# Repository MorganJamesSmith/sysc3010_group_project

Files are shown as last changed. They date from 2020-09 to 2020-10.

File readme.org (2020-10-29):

#+title: SYSC3010 Group Project
* Table of Contents                                          :TOC_1:noexport:
- [[#symptom-monitoring-door-system][Symptom monitoring Door System]]
- [[#possible-hardware][Possible hardware]]
- [[#group-expectations][Group Expectations]]
- [[#group-roles][Group Roles]]
- [[#weekly-meeting-guidelines][Weekly Meeting Guidelines]]
- [[#project-meeting-notes][Project Meeting Notes]]

* Symptom monitoring Door System
** Terminology
To keep a consistent style please use the following terms. No synonyms please
- Door Node
- Control Server
  - Users have: Accounts
- Security Badge
- NFC security badge reader
- infrared temperature sensor
- electronic lock actuator
** Description
The purpose of this system is to increase security and safety of
secured locations, like offices. The system will attempt to prevent
the spread of illness by limiting the number of people which can enter
the building, and by preventing people with a high body temperature
from entering the building.

This system will be mounted on the entrances and exits of a
building. The system will be modular to allow an arbitrary number of
nodes to be added.

The system will display a green light at the entrance if it is
accepting people. The light will turn red when the area is closed or
if there are too many people inside.

If the light is green, the user will present their NFC security card
to the system. The system send a message containing a unique user ID
to a server. The server will use it'd database to determine if the
user is authorized and if the user had previously shown symptoms to
the system within the last 14 days. The server will then notify the
door with the results of the query.

If the user has not already been denied, the system will then take the
user's temperature. If the temperature is above the threshold, they
can try again in 1 minute. If they fail 3 times in a row, they will be
forbidden access, and the operator of the system will have the option
to automatically deny them entry for the duration of a quarantine
period.

Every access attempt, including the associated temperature reading and
user ID, is sent to the server to be logged in a database.

If the temperature is below the threshold, and they have access, the
door will open.

Users will also have to present their NFC card to the door to leave
the building. By tracking users entering and exiting the building, the
server will know how many people are in the building.

The central server will also provide a GUI available to the buildings
security team. This GUI will allow security officers to manually
update the status of individuals in case a door must fall back to
manual operation. It will also allow the security team to modify who
has access to the building. For example, if someone receives a
negative test result for COVID-19, their access to the building could
be restored.

** Hardware
- 3D printed scale model of door
- Servo
- Contact-less Temperature Sensor
- NFC reader + cards
- Raspberry Pi's
** Requirements
*** Computer Components [3/3]
- [X] Computer per student
  - Computer for each entrance and exit
  - Database computer
- [X] computer in standalone mode
  - Interface for security team
    - Allow manual modification of user status
    - View temperature information on each person
- [X] computer in headless mode
  - Computers at entrances and exits
*** Hardware Components [2/3]
- [X] Actuator
  - Door opener
- [X] one sensor per student
  - Temperature probes
- [ ] Feedback loop
  - Door opens in response to temperature
*** Software Components [5/7]
- [X] Database
  - Number of people inside building
  - Uniquely identify people via smart card
- [X] Computer hosting database does something else
  - Runs GUI
- [ ] Periodic Timing Loop
  - Restrict access to when building is open
- [ ] Data processing
  - Access control
  - View interaction history
- [X] Notifications
  - Notify on failure and when near capacity
  - Notify if known infected people try to enter
- [X] Communication (through thingspeak)
  - Synchronize Database
- [X] GUI
  - See security team interface

* Possible hardware
** Temperature Sensor
- [[https://www.melexis.com/en/product/MLX90614/Digital-Plug-Play-Infrared-Thermometer-TO-Can][MLX90614]]
    - Very popular IR thermometer in TO-can
    - MLX90614ESF-DAA is the medical version, MLX90614ESF-BAA is the non medial
      3 V version
    - In stock at [[https://www.sparkfun.com/products/9570][SparkFun]]
- [[https://www.excelitas.com/product/tpis-1t-1256-l55-digipile-sensor][TPIS 1T 1256 L5.5]]
    - Designed for ear and forehead temperature measurement applications
    - 5 degree field of view
    - 67 counts per degree kelvin for a 40 ℃ object at 25 ℃ ambient, 8 counts per kelvin of noise for same conditions
    - Also measures ambient temp
    - Very annoying badly documented single wire digital interface, may be a bit
      tricky to get working directly on R-Pi but we could always use a small
      microcontoller like an ATTiny as a bridge
    - In stock at [[https://www.digikey.ca/en/products/detail/excelitas-technologies/TPIS-1T-1256-L5-5/5885902][DigiKey]]
** NFC
- [[https://www.nxp.com/docs/en/nxp/data-sheets/PN532_C1.pdf][Adafruit breakout for PN532]]
    - Seems to be compatible with [[https://github.com/nfc-tools/libnfc][libnfc]]
    - I2C, SPI and UART interfaces (Adafruit seems to strongly recommend SPI for
      use with the Raspberry Pi, but that could be a limitation of their
      CircuitPython library)
    - Comes with a MiFare Classic 1K card
    - Can get MiFare Classic in many different form factors (cards, keychains,
      rings, bracelets, etc.) from Adafruit or Sparkfun.
- [[https://www.nxp.com/products/rfid-nfc/nfc-hf/nfc-readers/explore-nfc-exclusive-from-element14:PNEV512R][NXP EXPLORE-NFC-WW]]
    - R-Pi hat based on [[https://www.nxp.com/docs/en/data-sheet/PN512.pdf][PN512]]
    - Cheaper than the Adafruit option and it's a nice hat form factor, but it
      is only available from [[https://canada.newark.com/nxp/explore-nfc-ww/nfc-add-on-board-raspberry-pi/dp/45X6356][Newark]]
      and they have not been reliable lately.
- Mario has a module based on the [[https://www.nxp.com/docs/en/data-sheet/MFRC522.pdf][MFR522]]
    - Slightly older chip than the others, but it should support everything we
      need
    - Might be hard to reliably find exactly the same board for other group
      members, it came as part of a kit and seems to be one of those Ali-Express
      type things. It would probably be possible to find other boards with the
      same chip though

* Group Expectations
- Slack messages will be responded to within 1 work day.
* Group Roles
** Sam
- Submit deliverables
** Sunny
** Mario
** Morgan
- Meeting Secretary
* Weekly Meeting Guidelines
- Happens every Tuesday @ 09:30
- Reminder should be sent in slack group chat the previous night
- Meeting is voice chat @ https://meet.jit.si/wewantbird
- Morgan takes notes and adds them to this document

1. Deliver Reports of what was accomplished since last meeting
2. Discuss any impediments
3. Discuss any impediments expected for the next week (example: lack
   of time due to midterms or travel)
4. Assign work for the next week
* Project Meeting Notes
** Meeting 9 <2020-10-28 Tue 18:00-22:00>
*** Minutes
Worked on design document.
*** TODOs
**** Everyone
- Write hardware stubs for your hardware
**** Sam
- Make electronic-lock-schematic.png slightly prettier
- Combine all class diagrams
- Add electronic lock to ?? schematic
- Create python classes to facilitate message transfer
**** Mario
- Flow chart stuff
  - Based off of class diagrams to be done by Sam
- Add more tests
- Reformat and sort tests
- Make list in problem statement a group of functional requirements (in terms
  of tasks or behaviors) instead of a list of parts
  - Prioritize the functional requirements
***** Sam's comment that might help you
Functional requirements:
- Control access to a building using security badges.
- Require users to present their security badge when they enter or exit the
  building in order to track the number of users in the building.
- Measure user's temperatures when they are entering the building in order to
  determine if they have possible symptoms.
- The door node should have a range sensor to determine whether users are in
  an appropriate position for a temperature reading.
- Do not allow more users to enter the building if the a preset maximum
  capacity has been reached.
- An multicoloured LED at each door node should indicate be used to indicate
  the status of the door node. The LED should be normally red when the door is
  locked and should change to green when the door is unlocked. The LED should
  be orange when in the process of taking a temperature reading if the user is
  not within an appropriate range of the temperature sensor.
**** Sunny
- Please write a description of the database schema
- Update database schema
- End-to-end tests
- Create database test stub
** Meeting 8 <2020-10-20 Tue 09:30>
*** Agenda
- Design Peer Review Integration
** Meeting 7 <2020-10-13 Tue 09:30>
*** Minutes
- Sam demoed his ThingSpeak code (very cool, much wow)
- Determined project design schedule
*** Project Design Roles
- flow chart for testing
**** Sam
- demo plan 3
- design overview text
- software design text
- Hardware design text
- temperature sensor
  - relevant hardware specification
  - test plan 2 a
- communication protocol table
- Related Class diagrams
- door node circuit diagram
**** Sunny
- Problem statement
- Project Update
- Database table design (help from Sam)
- Related Class diagrams
- test plan demo plan 1
- test plan demo 2 b
**** Mario
- NFC
  - relevant hardware specification
  - test plan 2 a
- Related Class diagrams
- flow chart for door interface
- flow chart for server:door messaging
**** Morgan
- motor
  - relevant hardware specification
  - test plan 2 a
- UML Architectural diagram
- Message sequence diagram(s)
- Related Class diagrams
** Meeting 6 <2020-10-06 Tue 09:30-10:10>
*** Minutes
- preliminary project design discussions
** Meeting 5 <2020-10-01 Thu 08:30-10:15>
- Reviewed proposal feedback and made changes
** Meeting 4 <2020-09-29 Tue 09:30-11:30>
*** Agenda
- Review proposal draft together
*** Minutes
- We reviewed the proposal and made some changes
*** TODOs
- Everyone: Touch up proposal as we discussed
- Morgan: Email the prof asking if we should include the actors in our
  deployment diagram
** Meeting 3 <2020-09-22 Tue 09:30-11:00>
*** Agenda
- Research project concepts
  - Look into hardware price/availability/complexity
*** Completed
- Finalized Project Idea
*** TODOs
- Everyone: Review proposal draft posted on Monday and bring written
  comments to next meeting
- Sam: Update readme with hardware research
- Morgan: Email Prof to confirm our project concept is approved
**** Proposal
***** Timeline
****** Content
<2020-09-27 Sun 12:00>
****** Latex formatting + send PDF to slack
<2020-09-28 Mon>
***** Sunny
- Executive Summary
  - Problem Statement
  - Motivation
  - Objective
  - Goals
  - Scope
***** Morgan
- deployment diagram
- door usage diagram
- hardware block diagram
***** Sam
- Test Plan
- Milestones and Timeline
- Latex formatting
***** Mario
- proposed solution
  - Server database
  - GUI
  - Integrate Morgan's diagrams
** Meeting 2 <2020-09-18 10:00-12:20>
*** Agenda
- Discuss Project Ideas
- Finalizing team contract
*** Completed
- Team contract
- Initial draft of proposal of a door monitoring system
** Meeting 1 <2020-09-17 10:30-11:30>
- Assigned Morgan "Secretary" role for weekly meetings
- Assigned Sam "Submit deliverables" role
- Created meeting guidelines (found [[https://github.com/MorganJamesSmith/sysc3010_group_project/blob/master/readme.org#weekly-meeting-guidelines][here]])
- Discussed team contract
- Created a readme to track progress, expectations, and meeting notes
  (found [[https://github.com/MorganJamesSmith/sysc3010_group_project/blob/master/readme.org][here]])
- Scheduled Meeting 2
*** To be completed before meeting 2
- All members: Review
  https://github.com/MorganJamesSmith/sysc3010_group_project/blob/master/readme.org
  and provide comments
- All members: Review all project requirements (Fact check + add information to
  this readme)

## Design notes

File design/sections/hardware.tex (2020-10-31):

The door node is the hardware that will be located at each door. It consists of
a NFC security badge reader, infrared temperature sensor, time of flight range
sensor and electronic door lock, all connected to a Raspberry Pi.

Figure \ref{fig:door-node-schematic} shows a schematic of the door node.

\begin{figure}[!htb]
\centering
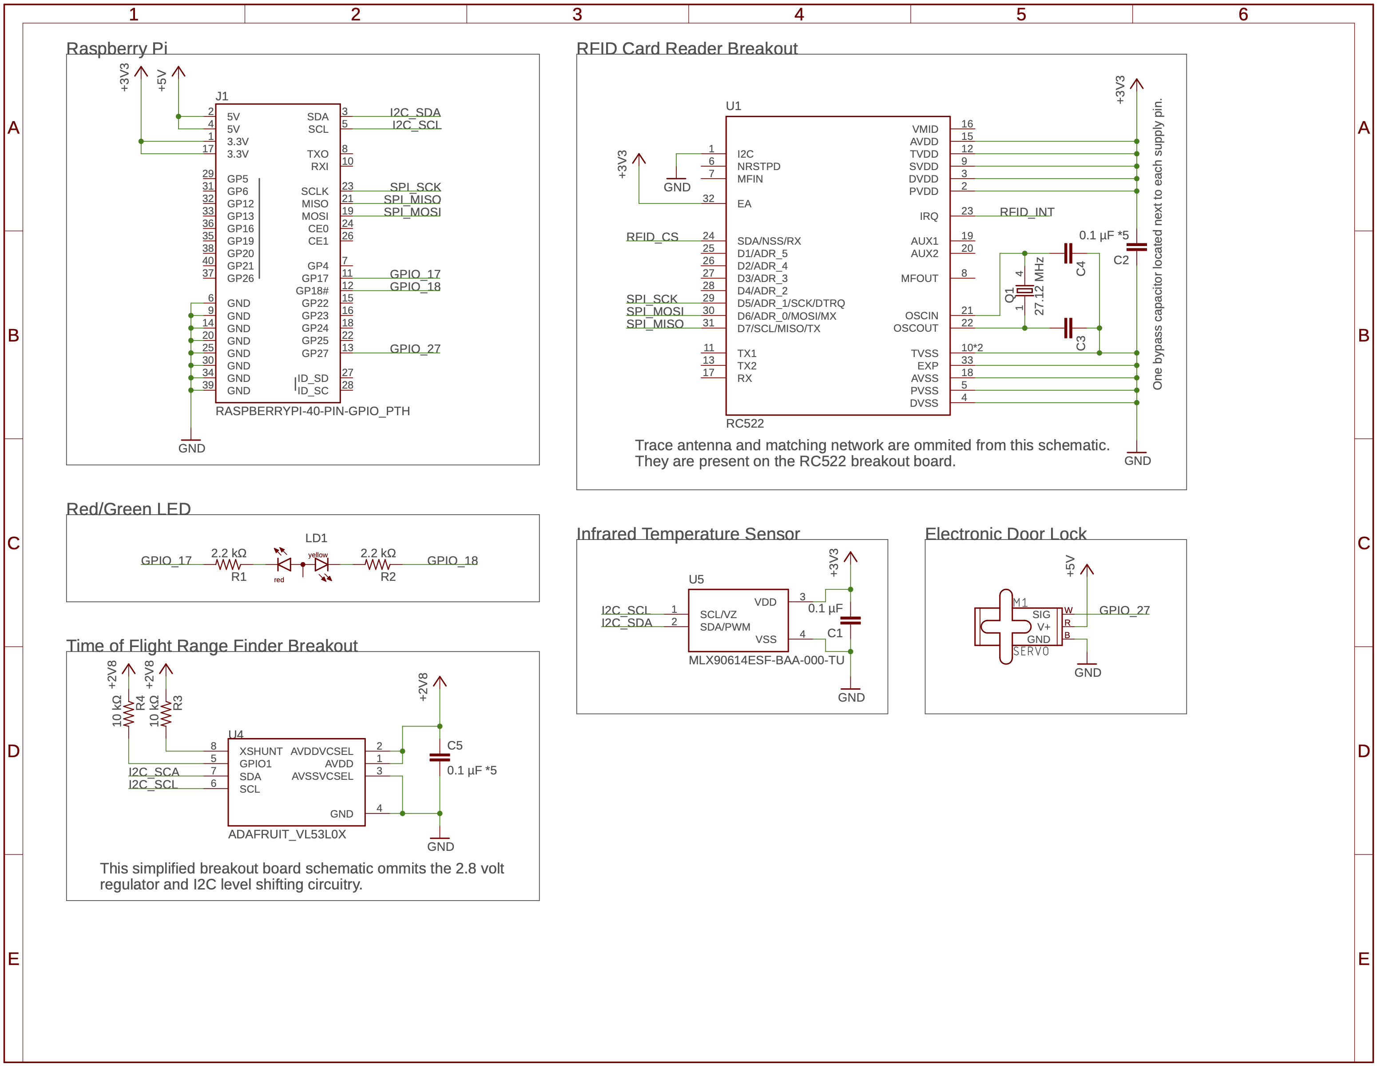
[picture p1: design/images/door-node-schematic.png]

\caption{Door Node Schematic}
\label{fig:door-node-schematic}
\end{figure}

\subsection{Infrared Temperature Sensor}

In order to detect fever we need to measure the temperature of the users of our
system. We have determined that a forehead temperature measurement using an
infrared temperature sensor is the best way to obtain sufficiently accurate
contactless temperature measurements.

We plan to use the MLX90614 thermopile from Melexis Technologies. This
temperature sensor was chosen after a comparison of available infrared
temperature sensors.

The MLX90614 offers medical grade accuracy within the temperature range expected
for human skin. It also provides accurate ambient temperature measurements. The
optics of the sensor provide a relatively narrow field of view which is
appropriate for measuring the fairly small target of a human forehead from a
reasonable range.

The MLX90614 can be powered from the Raspberry Pi's 3.3 volt rail and
features an I$^2$C serial interface, which is suitable for communication with a
Raspberry Pi.

Figure \ref{fig:ir-test-circuit} shows the test circuit for the infrared
temperature sensor.

\begin{figure}[!htb]
\centering
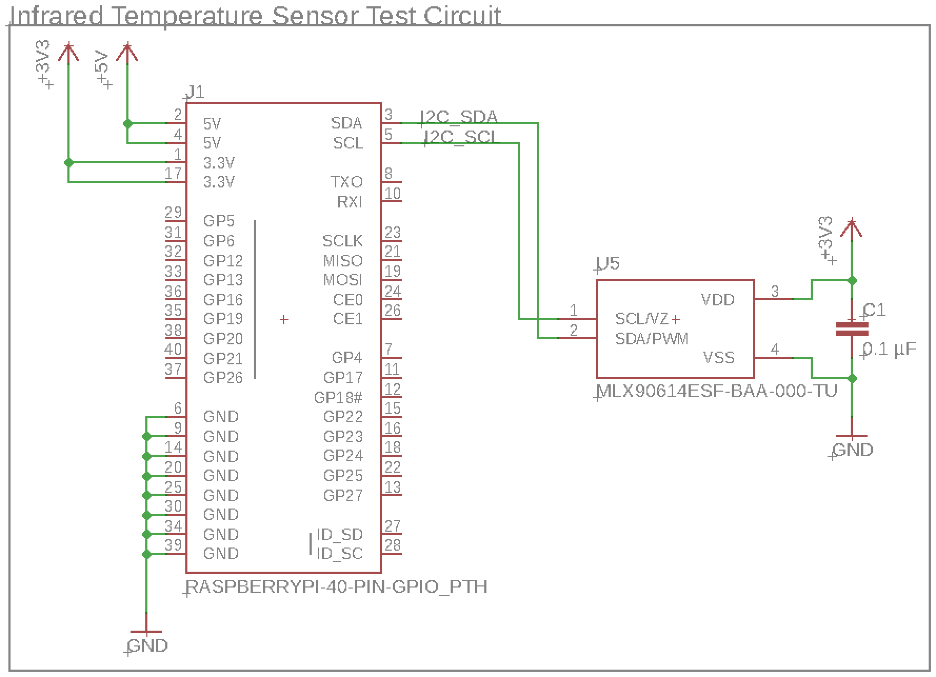
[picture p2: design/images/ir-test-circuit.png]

\caption{Test Circuit for Infrared Temperature Sensor}
\label{fig:ir-test-circuit}
\end{figure}

\subsection{NFC Security Badge Reader}

The MFRC522 RFID reader is the chosen device for the NFC security badge reader. 
It has an operating distance of up to 50 mm which means that the users will not have to place
the card almost touching the reader. the fact that it includes a programmable timer
is very useful as it can help avoid creating issues where it scans a card multiple times 
when doing a single swipe. As the reader is not meant to be the end all of deciding 
whether or not an employee will unlock the door it is therefore useful that the device
supports power down by software mode. When in lockdown or an employee attempts
to enter the building at full capacity it will be powered-down preventing entrance.  
The usage of serial peripheral interface helps as the badge reader functions quickly 
being able to handle data speeds up to 10 Mbit/s. 
It is powered by the 3.3 V DC power source of the Raspberry Pi.

For the below test circuit the differences between the test circuit and the actual demo circuit
are as follows. The T GPIO extension board used is coloured differently
and indicates GPIO rather than "\#" before the numbers. 
Other then those two changes the below circuit is identical to that which will be used in demonstrations.

\begin{figure}[!htb]
\centering
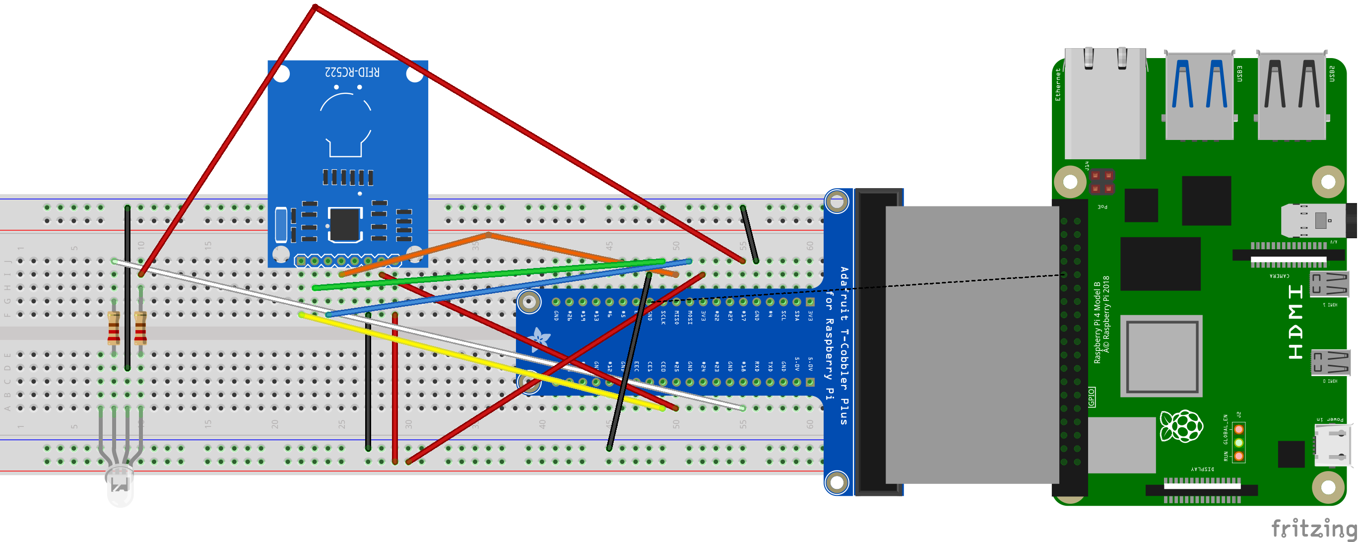
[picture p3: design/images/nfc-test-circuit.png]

\caption{Test Circuit for NFC Security Badge Reader}
\label{fig:nfc-test-circuit}
\end{figure}

\subsection{Electronic Door Lock}

The electronic door lock model will be powered by a servo motor. The chosen
servo motor is the Adafruit Micro Servo.  This servo has 180 degrees of motion
that can be traversed in 0.3 seconds.  The servo operates between 3V and 6V so
it can be powered through the Raspberry Pi's 5V line.

Figure \ref{fig:lock-test-circuit} shows the test circuit for the electronic
door lock.

\begin{figure}[!htb]
\centering
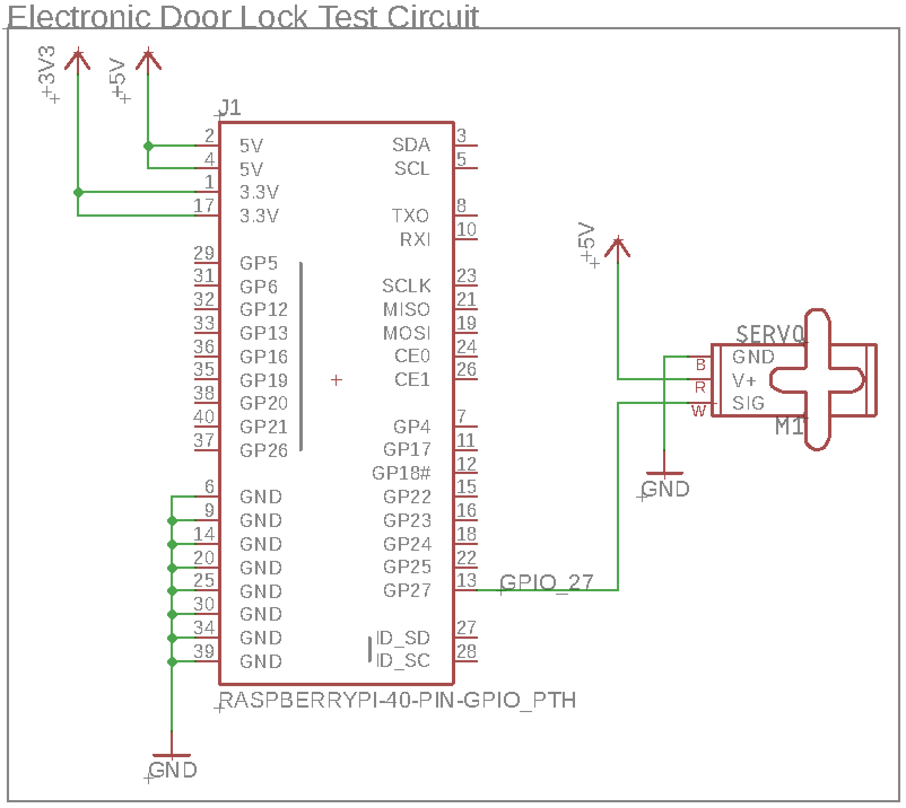
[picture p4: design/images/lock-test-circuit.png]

\caption{Test Circuit for Electronic Door Lock}
\label{fig:lock-test-circuit}
\end{figure}

\subsection{Time of Flight Range Sensor}

\begin{figure}[!htb]
\centering
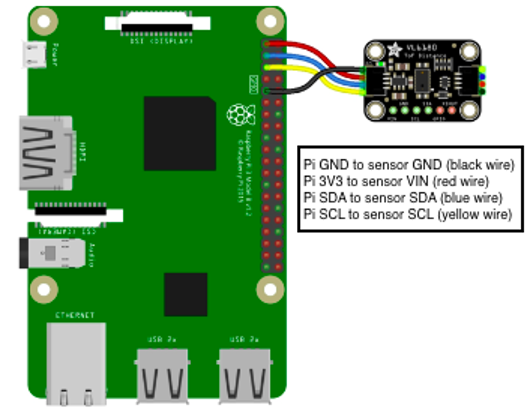
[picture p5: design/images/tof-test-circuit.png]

\caption{Test Circuit for Time of Flight Sensor}
\label{fig:tof-test-circuit}
\end{figure}

\subsection{Control Server}

The control server hardware will consist of a Raspberry Pi connected to a
monitor, keyboard and mouse.

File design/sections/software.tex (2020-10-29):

\subsection{Class Diagram}

\begin{figure}[!htb]
\centering

\caption{Class Diagram}
\label{fig:class-diagram}
\end{figure}

\subsection{Door Node}

\begin{figure}[!htb]
\centering
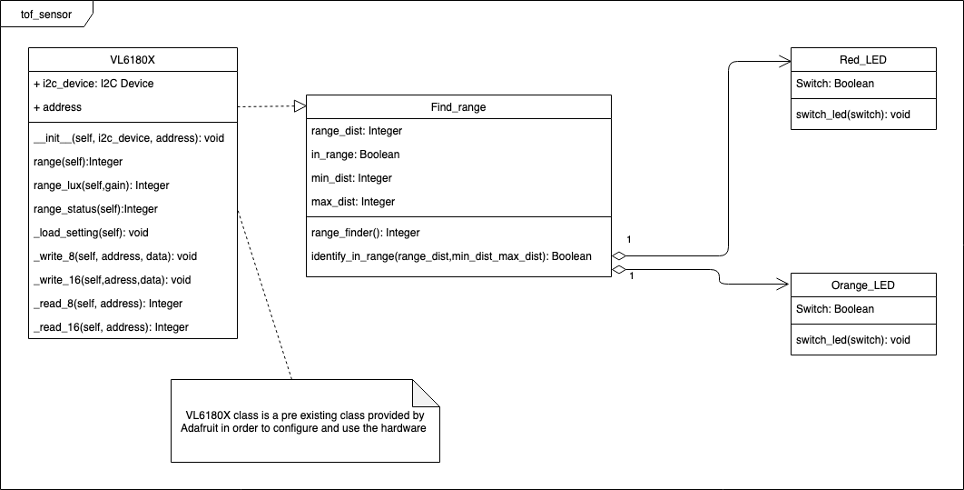
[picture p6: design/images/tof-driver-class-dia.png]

\caption{Class Diagram for Time of Flight Range Sensor Driver}
\end{figure}

\begin{figure}[!htb]
\centering
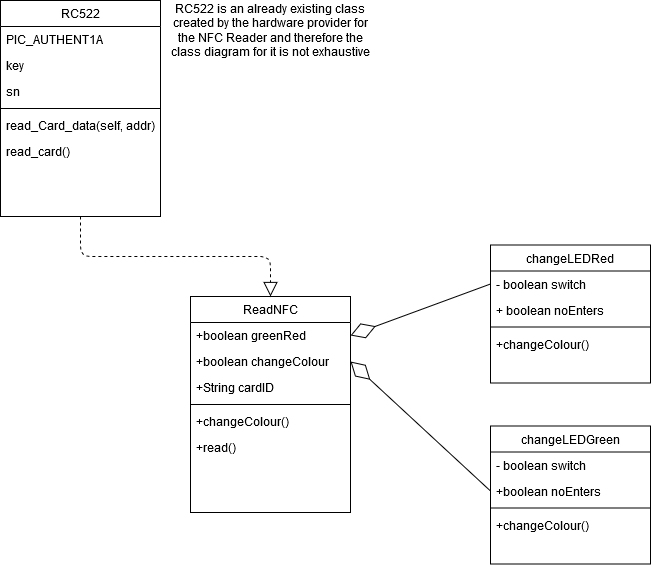
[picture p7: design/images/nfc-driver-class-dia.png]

\caption{Class Diagram for NFC Security Badge Reader Driver}
\end{figure}

\begin{figure}[!htb]
\centering
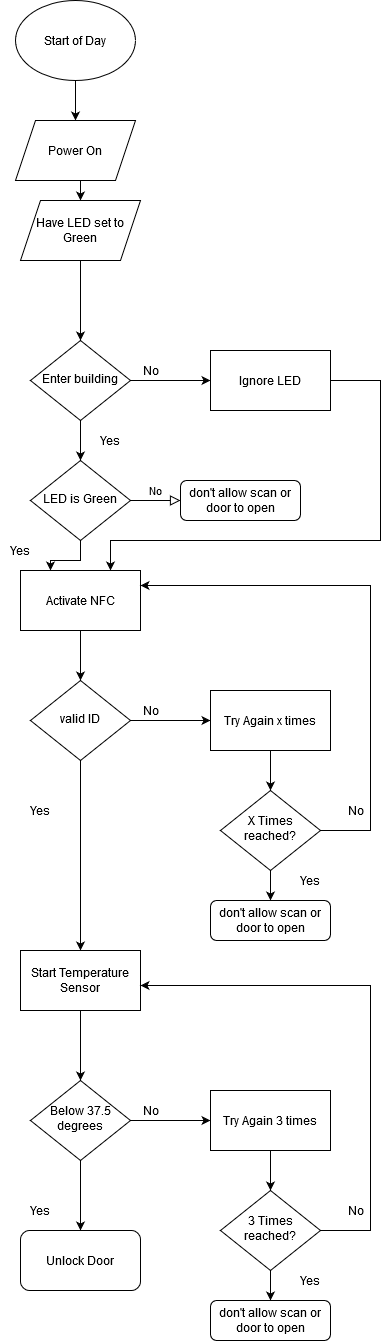
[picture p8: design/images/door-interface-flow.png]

\caption{Flow of Door Node Software}
\end{figure}

\subsection{Control Server}

\begin{figure}[!htb]
\centering
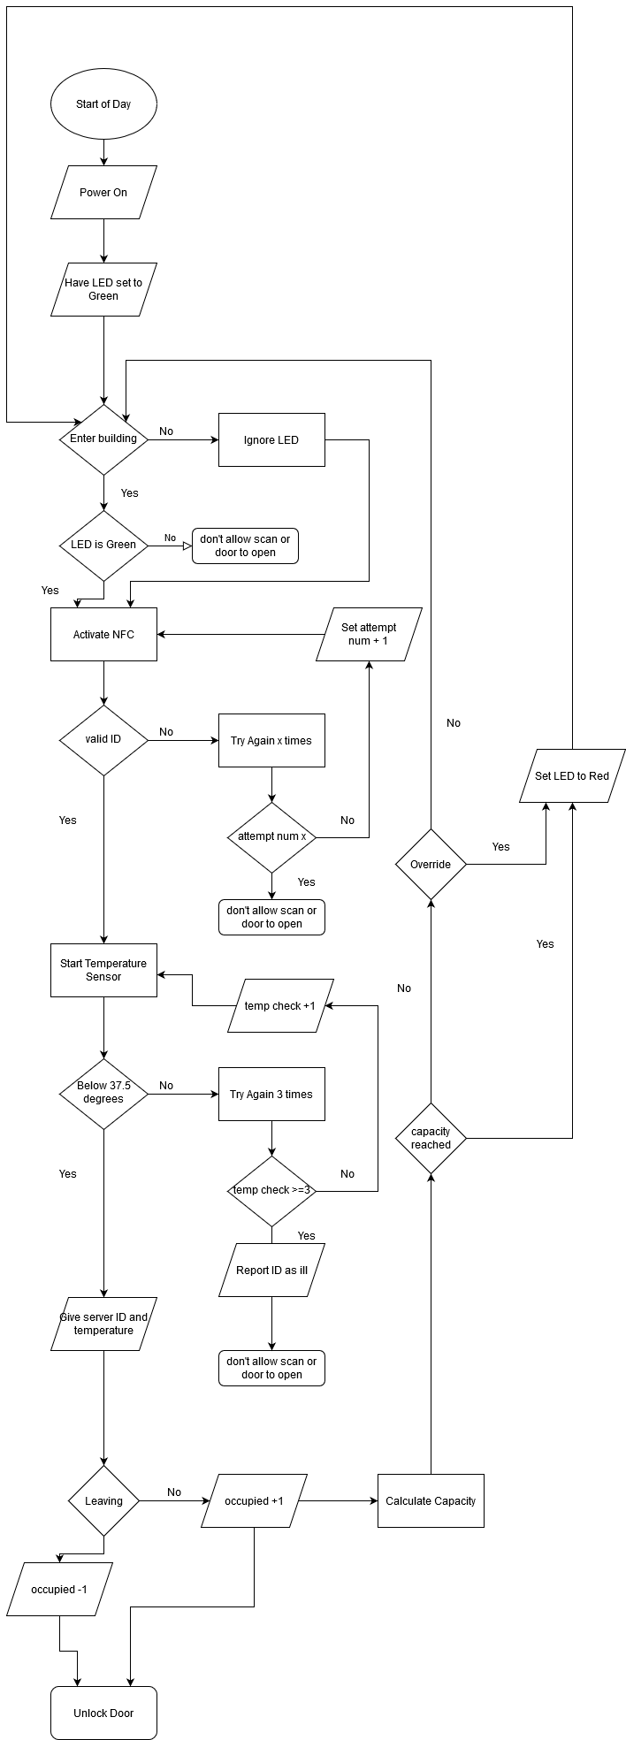
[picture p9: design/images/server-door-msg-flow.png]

\caption{Flow of Communication Between Control Server and Door Node}
\end{figure}

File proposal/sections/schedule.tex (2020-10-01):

\subsection{Timeline}

Table \ref{table:timeline} shows important submission deadlines and when we plan
to have major milestones completed.

\begin{table}[!hbt]
\renewcommand\arraystretch{1.4}\arrayrulecolor{LightSteelBlue3}
\captionsetup{singlelinecheck=false, font=blue, labelfont=sc, labelsep=quad}
\caption{Timeline}\vskip -1.5ex
\begin{tabular}{@{\,}r <{\hskip 2pt} !{\foo} >{\raggedright\arraybackslash}p{10cm}}
\toprule
\addlinespace[1.5ex]
2020-10-02 & Submission: Project Proposal\\
2020-10-11 & Milestone: Complete Initial Research\\
2020-10-14 & Milestone: Complete Communication Code\\
2020-10-23 & Submission: Project Design\\
2020-11-01 & Reflection: Re-evaluate Project Timeline\\
2020-11-01 & Milestone: Complete Door Model\\
2020-11-08 & Milestone: Complete Hardware Interface Code\\
2020-11-15 & Milestone: Complete Application Code\\
2020-11-22 & Milestone: Complete User Interface Code\\
2020-11-25 & Submission: Code Peer Review\\
2020-12-09 & Submission: Final Report\\
\end{tabular}
\label{table:timeline}
\end{table}

\subsection{Milestones}

\paragraph{Complete Initial Research}
By this point we should have completed all of out research in order to select
what hardware and libraries we would like to use for our project.

\paragraph{Complete Hardware Interface Code}
By this point all of the code responsible for interfacing with hardware and all
of the associated test stubs and applications should be complete. Work on this
milestone can be done in parallel with work on the communication and application
code.

\paragraph{Complete Communication Code}
By this point all of the code for exchanging information between door
nodes and the control server as well as all of the associated test stubs and
applications should be complete. Work on this milestone can be done in parallel
with work on the hardware interface and application code.

\paragraph{Complete Door Model}
By this point a 3D printed model door will be attached to a servo
attached to a Raspberry Pi with appropriate drivers.

\paragraph{Complete Application Code}
By this point all of the application level code should be complete and we should
be performing integration testing. Work on this milestone can be done in
parallel with work on the hardware interface and communication code.

\paragraph{Complete User Interface}
By this point the graphical user interface should be complete. We should be
performing integration testing of our complete system. Work on this milestone
can be done in parallel with work on the application code.

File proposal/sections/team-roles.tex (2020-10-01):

\subsection*{Sam}
\begin{itemize}
    \item Infrared Temperature Sensor
    \item ThingSpeak Communication
\end{itemize}

\subsection*{Sunny}
\begin{itemize}
    \item Database
    \item Data Processing
    \item Request Handling
\end{itemize}

\subsection*{Mario}
\begin{itemize}
    \item NFC Security Badge Reader Drivers
    \item Door Node User Interface
\end{itemize}

\subsection*{Morgan}
\begin{itemize}
    \item Operator GUI
    \item Make a prototype door actuator
    \begin{itemize}
        \item Servo drivers
        \item 3D printed door
    \end{itemize}
\end{itemize}

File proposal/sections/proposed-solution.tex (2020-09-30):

\subsection{Deployment Diagram}



\subsection{Communication Between Nodes}
The door nodes will communicate with with the control server using ThingSpeak.
They will send send messages to the control server on each user interaction and
the control server will provide information to them on whether users should be
granted access and what the door node's LED should show.

\subsection{Door Nodes}
The door nodes are Raspberry Pis that are set up in headless mode. The door
nodes are the  main points of interaction for the system, they have an NFC
security badge reader, an infrared temperature sensor and an electronic lock
actuator. An LED is connected to each of the door nodes that can be illuminated
in red or green to indicate whether people are allowed to enter the area.

% \subsubsection{Hardware Block Diagram for Door Hardware}

\subsubsection{Usage Diagram for Door}



\subsubsection{Sensors}
The infrared temperature sensor is central to the safety of the location
and why the system exists. It can measure the temperature of an individual
without physically touching them. The temperature information will be
communicated to the control server which can use it to determine if the users
has a fever and, if they do, will deny them access.

The NFC security badge reader is used to identify users. The control server will
keep track of users, including their access permissions and history of possible
symptoms, based on their security badges.

\subsubsection{Actuator}
The door will be unlocked by an electronic lock actuator attached to it. The
actuator will be controlled based on permission being granted by the control
server. The electronic lock by default will require an NFC security badge when
entering the building or leaving it. However, there will be failsafes so that if
there is a power outage or emergency it can be kept either locked or unlocked.

\subsection{Control Server}
The control server will be a Raspberry Pi connected to a monitor, keyboard and
mouse. The control server will maintain the database and will be responsible for
making decisions on whether to grant access to individuals based on the
configured access controls, the sensor data reported by the door nodes and the 
number of people currently in an area. 

The control server will also have a user interface that can be used for managing
the system.

\subsubsection{Database}
The database will contain the information about the individuals with valid
security badges. The database records will include information the temperature
measurements and the times at which people entered and left the building as well
as information about the access policy for entering the building.

\subsubsection{Graphical User Interface}
The Graphical User Interface (GUI) of the control server will appear as a table
with menus for options for the operator to view and interact with the database 
and the control server in a visually clear fashion. This includes being able to
set ranges for temperature, override the current LED colours and approving
quarantining.

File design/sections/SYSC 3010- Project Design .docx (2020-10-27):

SYSC 3010- Sunny Project Design Components

Problem Statement:

Our access control system will be designed to meet the needs of employers to look after the safety of their employees. The scope of this project is to provide employers with an access control system that grants access to employees entering the workplace based on their measured body temperature. As studies show that fever (< 39.1 °C) is the most frequent symptom in more than 50% of COVID-19 cases [1 (https://www.cebm.net/covid-19/in-patients-of-covid-19-what-are-the-symptoms-and-clinical-features-of-mild-and-moderate-case/)] our system also blocks access to employees with a body temperature of over 39.1 °C for 14 days to prevent the spread of COVID-19 in the workplace. Additionally, our system adheres to social distancing guidelines implemented by the government by keeping track of the number of people on the premises and restricts employees from entering the building when the maximum threshold for the workplace has been attained. Although not in the scope of the project, our system would work with employers to comply with their standards and constraints to provide their employees access to a COVID-19 free workplace. With many more features and benefits, implementing our system at workplaces around the world successfully helps in providing a COVID-19 free work environment for employees.

Our access control system is a technology-based solution using a data collection and management system whose primary features and their functionalities include:

- NFC security badge reader
  - Available at each door node at both entry and exit ways
  - Read valid NFC card ID and associate with employee ID
- Infrared temperature sensor
  - Available at each entry way
  - Measure the body temperature of an employee trying to enter the work premises
  - Alert control server in case of high temperature reading
- Time of flight distance sensor
  - Available at each entry way
  - Identify if the employee is standing at an ideal distance from the temperature sensor
- LED display
  - Available at each entry way
  - Display a green light at the entrance if accepting employee entry
  - Display a red circle light at the entrance when control server restricts access due to premises acquiring maximum threshold
  - Display orange light if employee in range of the temperature sensor
  - Display red light if employee not in range of temperature sensor
  - Display flashing green light if control server authorizes employee to access after having temperature recorded
  - Display flashing red light if control server unauthorizes employee from accessing the building after having temperature recorded
- Electronic door lock
  - Available at each door node at both entry and exit ways
  - Unlock only when control server authorizes the employee to enter/exit premises
  - Locked when control server prevents access to employees with recorded fever temperatures
  - Locked at entry ways when control server restricts access due to premises acquiring maximum threshold
- Control server
  - Able to access all door nodes
  - Able to access database and available tables
  - Identifies number of people entering and exiting the premises
  - Initializes access restriction when maximum threshold of premises is acquired
- Database
  - Properly organized tables with appropriate entries for each individual field
  - Properly formatted values for sensor recorded data fields
  - Records of the temperature readings of all employees are accessible for at least 14 days
- GUI
  - Able to add new employee information
  - Able to view details of all employees based on NFC security card user id and employee id
  - Able to approve quarantine period initiated by the control server for individual employees

Database Table schema:

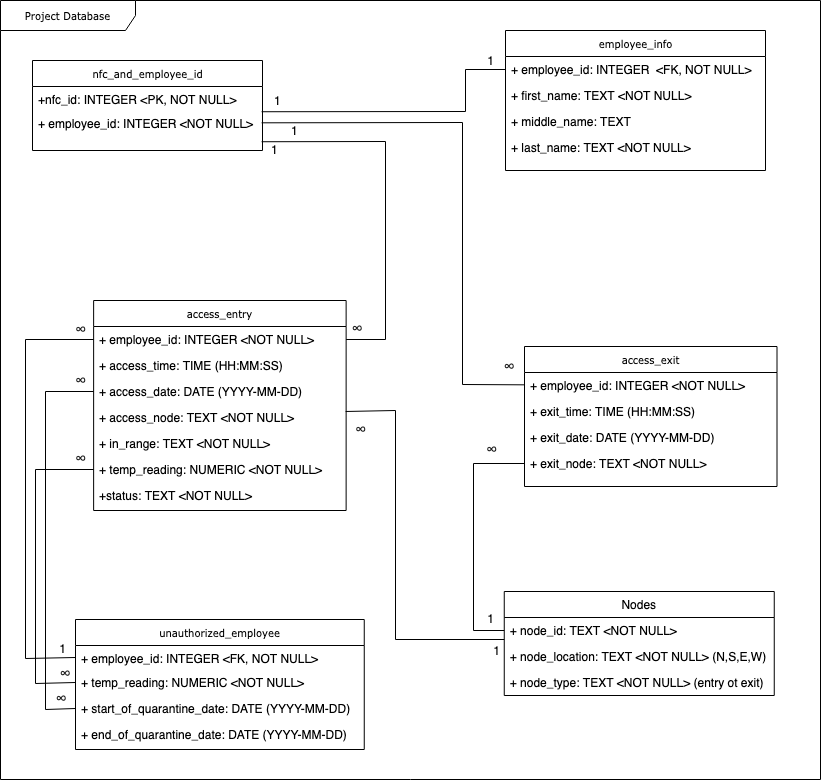
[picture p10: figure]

Class Diagram for Time of Flight sensor (is this also the software interface schematics?):

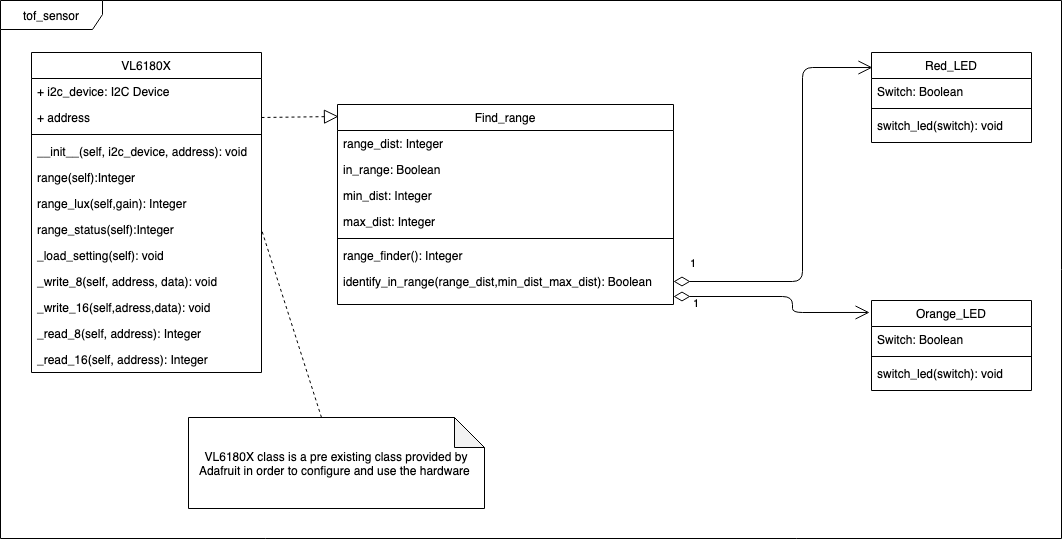
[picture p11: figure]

Hardware Design:

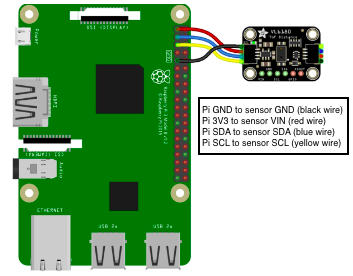
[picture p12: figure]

Test Demo Plan 1:

Hardware requirements:

- Setup Raspberry Pi’s in headless mode
- Connect sensors to Raspberry Pi’s
- If available, connect LED displays to Raspberry Pi

Software requirements:

- Set up Thingspeak channel
- Hard code sensor signal communication to Thingspeak
- Have test stubs which emulate the functionality of the hardware components ready

Entry access

Scenario 1: employee with valid NFC card, normal body temperature and ideal distance away from temperature sensor at entry node

Features to be tested:

- Communication between the NFC card reader and Thingspeak
- Communication between control server and Thingspeak
- Communication between Time of Flight range finder and Thingspeak
- Communication between LED display and Thingspeak
- Communication between Temperature sensor and Thingspeak
- Communication between control server and database
- Communication between Thingspeak and the electronic lock at entry node

Test scenario steps:

1. Control server uses Thingspeak to send the LED display a signal to display green light to indicate door node accepting entries
2. NFC reader identifies NFC id card being tapped and notifies control server of access attempt
3. NFC reader identifies tapped NFC card id and reports the id to the control server
4. Control server recognizes employee id based on NFC card id
5. Control server signals the rangefinder to identify if employee in range of temperature sensor through Thingspeak
6. Range finder reports back to the control server with the results and displays orange light
7. When in range, the control server sends a signal to the temperature sensor to measure employee body temperature through Thingspeak
8. Temperature sensor sends the recorded temperature to the control server using Thingspeak
9. Control server saves the recorded temperatures and other required information into the database
10. Control server compares recorded temperature to acceptable temperature range
11. If in acceptable temperature range, control server authorizes employee to enter building through Thingspeak
12. Control server sends a signal to the led display to display a flashing green light to indicate employee’s access has been authorized
13. Control server signals the electronic lock to unlock and adds 1 to number of people on the premises through Thingspeak
14. Control server uploads the additional entry attempt recorded data to database

Expected test scenario result: proper communication between nodes and control server occurred to authorize employee access to the workplace.

Scenario 2: employee with valid NFC card, normal body temperature and not in ideal distance range away from temperature sensor at entry node

Features to be tested:

- Communication between the NFC card reader and Thingspeak
- Communication between control server and Thingspeak
- Communication between Time of Flight range finder and Thingspeak
- Communication between LED display and Thingspeak
- Communication between Thingspeak and the electronic lock at entry node

Test scenario steps:

1. Control server uses Thingspeak to send the LED display a signal to display green light to indicate door node accepting entries
2. NFC reader identifies NFC id card being tapped and notifies control server of access attempt
3. NFC reader identifies tapped NFC card id and reports the id to the control server
4. Control server recognizes employee id based on NFC card id
5. Control server signals the range-finder to identify if employee in range of temperature sensor through Thingspeak
6. Range finder reports back to the control server with the results and displays red light to let employee know to stand in ideal range away from the temperature sensor
7. Control server signals electronic lock to stay locked through Thingspeak

Expected test scenario result: proper communication between nodes and control server occurred to let the employee know to stand in an ideal distance range away from the temperature sensor.

Scenario 3: employee with valid NFC card, body temperature over 39.1 °C and in ideal distance range away from temperature sensor at entry node

Features to be tested:

- Communication between the NFC card reader and Thingspeak
- Communication between control server and Thingspeak
- Communication between Time of Flight range finder and Thingspeak
- Communication between LED display and Thingspeak
- Communication between Temperature sensor and Thingspeak
- Communication between the GUI and Thingspeak
- Communication between control server and database
- Communication between Thingspeak and the electronic lock at entry node

Test scenario steps:

1. Control server uses Thingspeak to send the LED display a signal to display green light to indicate door node accepting entries
2. Identify tapped NFC card id
3. Notify control server of access attempt
4. NFC reader recognizes employee id based on NFC card id and reports to control server through Thingspeak
5. Control server signals the range-finder to identify if employee in range of temperature sensor through Thingspeak
6. Range finder reports back to the control server with the results and displays orange light if employee in range of the temperature sensor and red light if employee not in range
7. When in range, the control server sends a signal to the temperature sensor to measure employee body temperature through Thingspeak
8. Temperature sensor sends the recorded temperature to the control server using Thingspeak
9. Control server saves the recorded temperatures and other required information into the database
10. Control server compares recorded temperature to acceptable temperature range
11. If not in ideal temperature range, control server restricts employee from entering the building through Thingspeak
12. Control server sends a signal to the led display to display a flashing red light to indicate employee’s access has been unauthorized
13. Control server sends a quarantine approval notification to the GUI through Thingspeak
14. User approves the quarantine period notification
15. Approval is sent to the control server through Thingspeak from the GUI
16. Control server adds the employee information and recorded data to unauthorized employee table in the database and marks entry access date as the start of quarantine date
17. Using Thingspeak the control server signals the electronic lock to stay locked
18. Control server uploads the additional entry attempt recorded data to database

Expected test scenario result: proper communication between nodes and control server occurred to unauthorize employee access to workplace.

Exit access

Scenario 1: employee with valid NFC card and at exit node

Features to be tested:

- Communication between the NFC card reader and Thingspeak
- Communication between the control server and Thingspeak
- Communication between Thingspeak and the electronic lock at exit node

Test scenario steps:

1. NFC reader identifies NFC id card being tapped and notifies control server of exit attempt
2. NFC reader identifies tapped NFC card id and reports the id to the control server
3. Control server recognizes employee id based on NFC card id
4. Control server logs the data recorded for the exit attempt and updates the database
5. Control server signals the electronic lock to unlock and subtracts 1 from the number of people on the premises through Thingspeak

Expected test scenario result: employee successfully exits the building

Test Demo Plan 2a:

Test ID | Test Name/ Description | Test Setup | Expected Result | Actual Result
1 | Orange_LED function activated | Have LED display set up with the Raspberry Pi connected to monitor | RGB LED displays Orange
2 | Red_LED function activated | Have LED display set up with the Raspberry Pi connected to monitor | RGB LED displays Red
3 | Switch between orange and red LED’s | Have LED display set up with the Raspberry Pi connected to monitor | RGB LED initially displays orange and then switches to display red
4 | Switch between red and orange LED’s | Have LED display set up with the Raspberry Pi connected to monitor | RGB LED initially displays red and then switches to display orange
5 | VL6180X module activated | Have sensor connected to the Raspberry Pi and connect raspberry pi to a display | Display prints out initial reading
6 | VL6180X module activated and Range_Find class used to display multiple range recordings | Have sensor connected to the Raspberry Pi and connect raspberry pi to a display. Keep moving hand over the sensor to be able to measure range. | Display prints out different readings recorded from moving hand over the sensor

Test Demo Plan 2b:

Following features are to be tested in order to test the integrity of the database:

- Control server populating right tables
- Proper formatted data uploaded to appropriate fields
- Records of the temperature readings of all employees are accessible for at least 14 days

Test scenario 1: populating sample test data access_entry table

Features to be tested:

- Control server populating right tables

Initial setup: set up Raspberry pi connected to monitor keyboard and mouse. Open command prompt on Raspberry Pi.

Test scenario steps:

1. Invoke SQLite by typing this command in the command prompt
  a. sqlite3
2. Open the database by typing this command
  a. .open project_database.db
3. Populate data to employee access_entry table
  a. INSERT INTO access_entry VALUES(19234,time(‘now’),date(‘now’), ”S_entry”, ”Yes”, 38.0, “Authorized”);
  b. INSERT INTO access_entry VALUES(19437,time(‘now’,’-12 minutes’),date(‘now’), ”E_entry”, ”Yes”, 38.3, “Authorized”);
  c. INSERT INTO access_entry VALUES(19632,time(‘now’,’-1 hour’),date(‘now’), ”N_entry”, ”Yes”, 39.2, “Unauthorized”);
  d. INSERT INTO access_entry VALUES(19957,time(‘now’,’-5 minutes’),date(‘now’), ”W_entry” ,”Yes”, 38.5, “Authorized”);
4. Query data using Select* command
  a. SELECT * FROM access_entry;

Expected test scenario result: table populated with test sample data and query outputs 19234|09:30:23|2020-10-26|S_entry|Yes| 38.0| Authorized

19437|09:18:23|2020-10-26|E_entry|Yes| 38.3| Authorized

19632|08:30:23|2020-10-26|N_entry|Yes| 39.2| Unauthorized

19957|09:25:23|2020-10-26|W_entry|Yes|38.5|Authorized

Test scenario 2: populating sample test data nfc_and_employer_id table

Features to be tested:

- Proper formatted data uploaded to appropriate fields

Initial setup: set up Raspberry pi connected to monitor keyboard and mouse. Open command prompt on Raspberry Pi.

Test scenario steps:

1. Invoke SQLite by typing this command in the command prompt
  a. sqlite3
2. Open the database by typing this command
  a. .open project_database.db
3. Populate data to employee access_entry table
  a. INSERT INTO access_entry VALUES(19234,time(‘now’),date(‘now’),”S_entry”,”Yes”, 38.0, “Authorized”);
  b. INSERT INTO access_entry VALUES(19437,time(‘now’,’-12 minutes’),date(‘now’),”E_entry”,”Yes”, 38.3, “Authorized”);
  c. INSERT INTO access_entry VALUES(19632,time(‘now’,’-1 hour’),date(‘now’),”N_entry”,”Yes”, 39.2, “Unauthorized”);
  d. INSERT INTO access_entry VALUES(19957,time(‘now’,’-5 minutes’),date(‘now’),”W_entry”,”Yes”, 38.5, “Authorized”);
4. Query the format of date and time data entries using Select command
  a. SELECT access_time, access_date FROM access_entry;

Expected test scenario result: table populated with test sample data and query outputs

09:30:23|2020-10-26

09:18:23|2020-10-26

08:30:23|2020-10-26

09:25:23|2020-10-26

Test scenario 3: populating sample test data access_entry table

Features to be tested:

- Records of the temperature readings of all employees are accessible for at least 14 days

Initial setup: set up Raspberry pi connected to monitor keyboard and mouse. Open command prompt on Raspberry Pi.

Test scenario steps:

5. Invoke SQLite by typing this command in the command prompt
  a. sqlite3
6. Open the database by typing this command
  a. .open project_database.db
7. Populate data to employee access_entry table
  a. INSERT INTO access_entry VALUES (19234, time(‘now’), date(‘now’), ”S_entry”, ”Yes”, 38.0, “Authorized”);
  b. INSERT INTO access_entry VALUES (19437, time(‘now’,’-12 minutes’), date(‘now’,-1 day’), ”E_entry”, ”Yes”, 38.3, “Authorized”);
  c. INSERT INTO access_entry VALUES (19632, time(‘now’,’-1 hour’), date(‘now’, ‘-3 days’), ”N_entry”, ”Yes”, 39.2, “Unauthorized”);
  d. INSERT INTO access_entry VALUES (19957, time(‘now’,’-5 minutes’), date(‘now’, ‘-7 days’), ”W_entry”, ”Yes”, 38.5, “Authorized”);
  e. INSERT INTO access_entry VALUES (19234, time(‘now’), date(‘now’, ‘-13 days’), ”S_entry”, ”Yes”, 38.0, “Authorized”);
  f. INSERT INTO access_entry VALUES (19437, time(‘now’,’-12 minutes’), date(‘now’,’-14 days’), ”E_entry”, ”Yes”, 38.3, “Authorized”);
  g. INSERT INTO access_entry VALUES (19632, time(‘now’,’-1 hour’), date(‘now’,’-14 days’), ”N_entry”, ”Yes”, 39.2, “Unauthorized”);
  h. INSERT INTO access_entry VALUES (19957, time(‘now’,’-5 minutes’), date(‘now’,’-15 days’), ”W_entry”, ”Yes”, 38.5, “Authorized”);
8. Query data using Select* command
  a. SELECT * FROM access_entry WHERE access_date > date(‘now’);

Expected test scenario result: table populated with test sample data and query outputs

19437|09:18:23|2020-10-25|E_entry|Yes| 38.3| Authorized

19632|08:30:23|2020-10-23|N_entry|Yes| 39.2| Unauthorized

19957|09:25:23|2020-10-19|W_entry|Yes|38.5|Authorized

19234|09:30:23|2020-10-13|S_entry|Yes| 38.0| Authorized

19437|09:18:23|2020-10-12|E_entry|Yes| 38.3| Authorized

19632|08:30:23|2020-10-12|N_entry|Yes| 39.2| Unauthorized

19957|09:25:23|2020-10-11|W_entry|Yes|38.5|Authorized

Project Update:

Looking back at the Timeline initiated in the proposal, #insert timeline here#

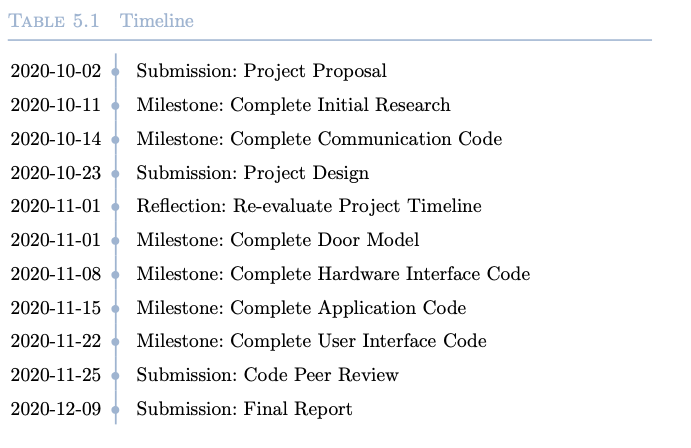
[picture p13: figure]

Our project group has been working really hard in meeting the project timeline. Although things didn’t go exactly as planned in the beginning of the term, our group has successfully met most of the milestones set up so far. As some of the submission dates have been postponed, our team continues to work towards achieving set tasks and hopefully have all the required hardware and software components ready and properly set up for the demo’s. So far, we haven’t had any roadblocks regarding individual assigned tasks. We don’t think re-balancing tasks is necessary as every team member has worked hard towards accomplishing their assigned tasks and has contributed to group submission with good quality work. We would consider ourselves to be well on track to accomplishing our goals set up for the project.

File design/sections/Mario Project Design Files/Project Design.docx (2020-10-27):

## Class Diagram


## Hardware Specification

Schematic of hardware : The T GPIO extension board used is coloured differently and indicates GPIO rather then # before the numbers. MFRC 522 RFID was selected due to it being available in a kit that I already had access to and having provided code.

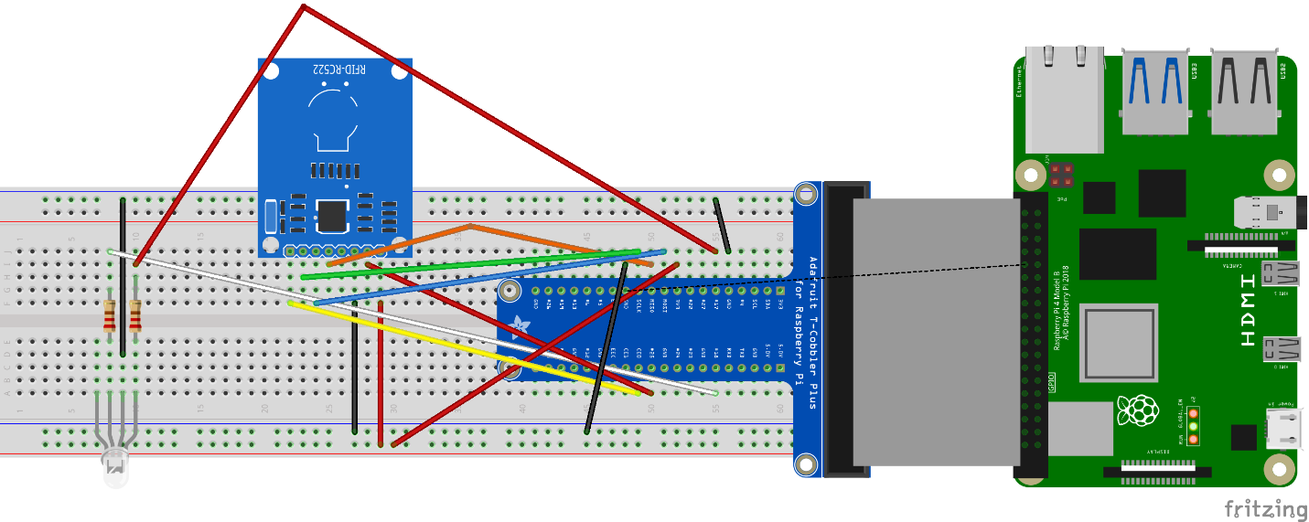
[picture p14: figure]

## Test Plan 2 a

Test ID | Test Name/Description | Test Setup | Expected Results | Actual results fill later
1 | Green RGB LED functions | Have breadboard set up | Green is shown on LED
2 | Red RGB LED functions | Have breadboard set up | Red is shown on LED
3 | Green RGB LED can change to red | Have breadboard set up | Initially green is shown on LED which then changes to red
4 | Red RGB LED can change to green | Have breadboard set up | Initially red is shown on LED which then changes to green
5 | MFRC 522 RFID Module activates | Have breadboard set up. Have a passive tag ready to wave in front | Pi prints out data on RFID tag
6 | MFRC 522 RFID Module can note separate ID | Have breadboard set up. Have two passive tags ready to wave in front | Pi prints out different data for each RFID tag swiped in front.
7 | MFRC 5222 RFID Module will not read when RGB LED is red | Have breadboard set up. Have a passive tag ready to wave in front | RGB LED is red and no data is printed out by the Pi.

## flow chart for door interface


## flow chart for server:door messaging


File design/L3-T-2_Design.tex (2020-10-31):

\documentclass[11pt,letterpaper]{article}
\usepackage[utf8]{inputenc}
\usepackage[top=2.54cm,bottom=2.54cm,left=4cm,right=2.5cm,headheight=14pt]{geometry}
\usepackage{graphicx}
\usepackage[hidelinks,bookmarksnumbered]{hyperref}
\usepackage[all]{hypcap}
\usepackage{fancyhdr}
\usepackage[calcwidth]{titlesec}
\usepackage{chngcntr}
\usepackage{bytefield}
\usepackage{booktabs}
\usepackage[x11names]{xcolor}
\usepackage{listings}
\usepackage[section]{placeins}
\usepackage[style=iso]{datetime2}
\usepackage{pgf-umlsd}
\usepackage{amsmath}
\usepackage{cite}
\usepackage[nottoc,numbib]{tocbibind}
\usepackage{colortbl}
\usepackage{caption}
\usepackage{textcomp}
\usepackage{listings}
\usepackage{longtable}
\usepackage{minted}
\usepackage[nobreak=true]{mdframed}

\surroundwithmdframed{minted}
\surroundwithmdframed{verbatim}

\DeclareCaptionFont{blue}{\color{LightSteelBlue3}}
\newcommand{\foo}{\color{LightSteelBlue3}\makebox[0pt]{\textbullet}\hskip-0.5pt\vrule width 1pt\hspace{\labelsep}}

\title{L3-T-2 Design Document}
\author{Samuel Dewan, Sunjeevani Pujari, Mario Shebib and Morgan Smith}

% Headers and footers
\pagestyle{fancy}
\fancyhf{}
\lhead{SYSC3010 Project Design Document}
\rhead{Group L3-T-2}
\rfoot{\thepage}

% More space around figures
\setlength\intextsep{18pt}
% Per section figure and table numbers
\counterwithin{figure}{section}
\counterwithin{table}{section}

% Colour links rather than putting a box around them
\hypersetup{
    colorlinks,
    linkcolor={black},
    citecolor={blue!50!black},
    urlcolor={blue!80!black},
}

% More space between table rows
\renewcommand{\arraystretch}{1.2}

% Section numbers in the margin
\newcommand{\marginsecnumber}[1]{%
    \makebox[0pt][r]{#1\hspace{6pt}}%
}
\titleformat{\section}
    {\sffamily\Large\bfseries}
    {\marginsecnumber\thesection}
    {0pt}
    {}
\titleformat{\subsection}
    {\sffamily\large\bfseries}
    {\marginsecnumber\thesubsection}
    {0pt}
    {}
\titleformat{\subsubsection}
    {\sffamily\normalsize\bfseries}
    {\marginsecnumber\thesubsubsection}
    {0pt}
    {}

% Draft watermark
\usepackage{eso-pic,graphicx}
\AddToShipoutPicture*{%
    \AtTextCenter{%
        \makebox(0,0)[c]{\resizebox{\textwidth}{!}{%
        \rotatebox{45}{\textsf{\textbf{\color{lightgray}DRAFT}}}}}
    }
}

\begin{document}
\frenchspacing

\pagenumbering{Alph}
\begin{titlepage}
\centering

\vspace*{\stretch{2}}

{\Huge \sffamily Project Design Document}

\vspace{\stretch{1}}
{\large \textbf{SYSC3010}}

{\large \textbf{Fall 2020}}

Prof. Cheryl Schramm

\vspace{\stretch{2}}

{\large \textbf{Group L3-T-2}}

Samuel Dewan

{\footnotesize samueldewan@cmail.carleton.ca}

Sunjeevani Pujari

{\footnotesize sunjeevanipujari@cmail.carleton.ca}

Mario Shebib

{\footnotesize marioshebib@cmail.carleton.ca}

Morgan Smith

{\footnotesize morgansmith@cmail.carleton.ca}

\vspace{\stretch{2}}

{\large \today}

\vspace{\stretch{3}}

\end{titlepage}

\pagenumbering{Roman}
\tableofcontents
\clearpage
\pagenumbering{arabic}

\section{Problem Statement}
\label{sec:problem-statement}
\input{sections/problem.tex}
\clearpage

\section{Design Overview}
\label{sec:design-overview}
\input{sections/overview.tex}
\clearpage

\section{Software Design}
\label{sec:software-design}
\input{sections/software.tex}
\clearpage

\section{Hardware Design}
\label{sec:hardware-design}
\input{sections/hardware.tex}
\clearpage

\section{Test Plan}
\label{sec:test-plan}
\input{sections/testing.tex}
\clearpage

\section{Project Update}
\label{sec:project-update}
\input{sections/progress.tex}
\clearpage

%\bibliography{references}{}
%\bibliographystyle{plain}
%\clearpage

\end{document}

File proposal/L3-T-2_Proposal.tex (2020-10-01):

\documentclass[11pt,letterpaper]{article}
\usepackage[utf8]{inputenc}
\usepackage[top=2.54cm,bottom=2.54cm,left=4cm,right=2.5cm,headheight=14pt]{geometry}
\usepackage{graphicx}
\usepackage[hidelinks,bookmarksnumbered]{hyperref}
\usepackage[all]{hypcap}
\usepackage{fancyhdr}
\usepackage[calcwidth]{titlesec}
\usepackage{chngcntr}
\usepackage{booktabs}
\usepackage[x11names]{xcolor}
\usepackage{listings}
\usepackage[section]{placeins}
\usepackage[style=iso]{datetime2}
\usepackage{pgf-umlsd}
\usepackage{amsmath}
\usepackage{cite}
\usepackage[nottoc,numbib]{tocbibind}
\usepackage{colortbl}
\usepackage{caption}
\usepackage{textcomp}

\DeclareCaptionFont{blue}{\color{LightSteelBlue3}}
\newcommand{\foo}{\color{LightSteelBlue3}\makebox[0pt]{\textbullet}\hskip-0.5pt\vrule width 1pt\hspace{\labelsep}}

\title{L3-T-2 Proposal}
\author{Samuel Dewan, Sunjeevani Pujari, Mario Shebib and Morgan Smith}

% Headers and footers
\pagestyle{fancy}
\fancyhf{}
\lhead{SYSC3010 Project Proposal}
\rhead{Group L3-T-2}
\rfoot{\thepage}

% More space around figures
\setlength\intextsep{18pt}
% Per section figure and table numbers
\counterwithin{figure}{section}
\counterwithin{table}{section}

% Colour links rather than putting a box around them
\hypersetup{
    colorlinks,
    linkcolor={black},
    citecolor={blue!50!black},
    urlcolor={blue!80!black},
}

% More space between table rows
\renewcommand{\arraystretch}{1.2}

% Section numbers in the margin
\newcommand{\marginsecnumber}[1]{%
    \makebox[0pt][r]{#1\hspace{6pt}}%
}
\titleformat{\section}
    {\sffamily\Large\bfseries}
    {\marginsecnumber\thesection}
    {0pt}
    {}
\titleformat{\subsection}
    {\sffamily\large\bfseries}
    {\marginsecnumber\thesubsection}
    {0pt}
    {}
\titleformat{\subsubsection}
    {\sffamily\normalsize\bfseries}
    {\marginsecnumber\thesubsubsection}
    {0pt}
    {}

% Draft watermark
\usepackage{eso-pic,graphicx}
\AddToShipoutPicture*{%
    \AtTextCenter{%
        \makebox(0,0)[c]{\resizebox{\textwidth}{!}{%
        \rotatebox{45}{\textsf{\textbf{\color{lightgray}DRAFT}}}}}
    }
}

\begin{document}
\frenchspacing

\pagenumbering{Alph}
\begin{titlepage}
\centering

\vspace*{\stretch{2}}

{\Huge \sffamily Project Proposal}

\vspace{\stretch{1}}
{\large \textbf{SYSC3010}}

{\large \textbf{Fall 2020}}

Prof. Cheryl Schramm

\vspace{\stretch{2}}

{\large \textbf{Group L3-T-2}}

Samuel Dewan

{\footnotesize samueldewan@cmail.carleton.ca}

Sunjeevani Pujari

{\footnotesize sunjeevanipujari@cmail.carleton.ca}

Mario Shebib

{\footnotesize marioshebib@cmail.carleton.ca}

Morgan Smith

{\footnotesize morgansmith@cmail.carleton.ca}

\vspace{\stretch{2}}

{\large \today}

\vspace{\stretch{3}}

\end{titlepage}

\pagenumbering{Roman}
\tableofcontents
\clearpage
\pagenumbering{arabic}

\section{Project Description}
\label{sec:project-description}
\input{sections/project-description.tex}
\clearpage

\section{Proposed Solution}
\label{sec:proposed-solution}
\input{sections/proposed-solution.tex}
\clearpage

\section{Team Roles}
\label{sec:team-roles}
\input{sections/team-roles.tex}
\clearpage

\section{Testing}
\label{sec:testing}
\input{sections/testing.tex}
\clearpage

\section{Schedule}
\label{sec:schedule}
\input{sections/schedule.tex}
\clearpage

%\section{Bibliography}
%\label{sec:bibliography}
\bibliography{references}{}
\bibliographystyle{plain}
\clearpage

\end{document}

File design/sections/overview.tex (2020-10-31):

\subsection{Architecture}

Our product it made up of two parts: the control server, and the door nodes.
Our product interacts with two types of actors: Operators and Users.

The control server maintains a database of operator profiles, operator logs,
user profiles, and interaction logs.  The control server will use the operator
profiles to validate users using the operator GUI.  Every action performed in
the operator GUI will be logged in the operator logs.  Operators can create and
modify user profiles.  When a user attempts to use a door node, their identity
is checked against their user profile.  Each interaction with a door node is
recorded in a user log.

\begin{figure}[!htb]
\centering

\caption{UML Architecture Diagram}
\label{fig:architecture-diagram}
\end{figure}

\subsection{Message Sequence Diagrams}

As seen in Figure \ref{fig:message-sequence-diagram}, all message sequences are
initiated by the Door Node sending an ACCESS\_REQUEST.  The Control Server can
reply with an ACCESS\_RESPONSE to immediately grant or deny access.  If the
Control Server doesn't have enough information to make a decision, it will send
INFORMATION\_REQUEST's until it has enough information to send an
ACCESS\_RESPONSE message.

These messages are built in a way that additional sensors could easily be added
to system.

Since there are separate Door Nodes for entrances and exits, the Control Server
can determine if a user is entering or exiting based on the Node ID.  If a Door
Node is to be used for both entering and exiting, it will be equipped with two
NFC Security Badge Readers.  The Door Node will use a separate Node ID for
interactions with each NFC Security Badge Reader.  The Control Server will view
this Door Node with two NFC Security Badge Readers as two separate Door Nodes.

When a user is entering the building, the Control Server will consult the
database to determine if the user is authorized to enter the building.  If the
the user is not authorized, the Control Server will respond with an
ACCESS\_RESPONSE message denying the user.  If the user is authorized, the
Control Server will respond with an INFORMATION\_REQUEST for the user's
temperature.  The door node will then respond with an INFORMATION\_RESPONSE
containing the user's temperature.  The Control Server will repeat the
INFORMATION\_REQUEST for temperature until a temperature not indicating a fever
is received, or the maximum number of tries is reached.  The Control Server
will then respond with an ACCESS\_RESPONSE message denying the user if it is
determined they might have a fever or granting access to the user if their
temperature is normal.  The Control server will then update the database.

When a user is exiting the building, the Control Server will immediately respond
with an ACCESS\_RESPONSE message granting access to the user.  The Control
Server will then use this information to update the database.

\begin{figure}[!htb]
\centering

\caption{Message Sequence Diagram}
\label{fig:message-sequence-diagram}
\end{figure}

\subsection{Communication Protocol}

Our communication protocol consists of two layers: a simple transport layer that
abstracts over ThingSpeak and an application layer that carries information
specific to our system.

\subsubsection{ThingSpeak Transport Layer}

The ThingSpeak transport layer is designed to provide an interface that
functions similarly to a TCP or UDP socket but uses ThingSpeak as a backend.

The ThingSpeak transport layer uses a single ThingSpeak channel to facilitate
communication between an arbitrary number of endpoints. Each entry posted to the
channel uses two ThingSpeak fields. The first contains a transport layer header
and the second contains the application layer data.

The ThingSpeak transport layer header is encoded as string in the first field of
a ThingSpeak channel entry. It contains three fields, which are separated by a
tab character.
\begin{itemize}
    \item Source Address: A string the uniquely identifies the device from which
          the message originates.
    \item Destination Address: A string the uniquely identifies the device for
          which the message is intended.
    \item Flags: A comma separated lists of flags.
\end{itemize}

The valid message flags are listed in table \ref{tab:ts-transport-flags}.

\begin{table*}[htb]
\centering
\begin{tabular}{ c | c | m{6.0cm} }
\toprule
Name & Encoded Value & Description\\
\midrule
Connection Request & conn\_req & Indicates that the message is a connection
request. If set, any other flags and the payload are ignored.\\
\bottomrule
\end{tabular}
\caption{Transport Layer Header Flags}
\label{tab:ts-transport-flags}
\end{table*}

In order to establish a connection, a client sends message to the server to
which it wishes to connect that has the conn\_req flag set. If the server
receives the message and wishes to accept the connection it will respond with a
messages that has the conn\_req flag set.

The second field of a ThingSpeak channel entry contains the application layer
message content encoded as a base 64 string.

\subsubsection{Application Layer}

The application layer protocol consist of five different message types, which
are listed in table \ref{tab:app-layer-messages}.

All message fields are encoded with network endianness (big endian).

\begin{table*}[htb]
\begin{tabular}{ l | l | l | p{4.5cm} }
\toprule
Sender & Receiver & Message & Data Format\\
\midrule
Door Node & Control Server & ACCESS\_REQUEST &
Transaction ID \newline Account ID\\
\hline
Control Server & Door Node & ACCESS\_RESPONSE &
Transaction ID \newline Access Request Response\\
\hline
Control Server & Door Node & INFORMATION\_REQUEST &
Transaction ID \newline Information Type\\
\hline
Door Node & Control Server & INFORMATION\_RESPONSE &
Transaction ID \newline Information Type \newline Information Value\\
\hline
Control Server & Door Node & DOOR\_STATE\_UPDATE & New Sate\\
\bottomrule
\end{tabular}
\caption{Application Layer Messages}
\label{tab:app-layer-messages}
\end{table*}

All messages start with a 32 bit integer Message Type field. The possible
message types are listed in table \ref{tab:message-types}.

\begin{table*}[htb]
\centering
\begin{tabular}{@{}ll@{}}
\toprule
Value               &   Description \\
\midrule
0x0                 &   Reserved for future use \\
0x1                 &   Access Request \\
0x2                 &   Access Response \\
0x3                 &   Information Request \\
0x4                 &   Information Response \\
0x5                 &   Door State Update \\
0x6 through 0xFFFF  &   Reserved for future use \\
\bottomrule
\end{tabular}
\caption{Message Type Values}
\label{tab:message-types}
\end{table*}

\paragraph{ACCESS\_REQUEST}
This message is sent by a door node in order to initiate an access request. The
message contains a transaction ID to identify this access request sequence. The
transaction ID is a 32 bit integer that should be unique for the door node that
is initializing the request. The message also contains the 128 bit identifier
from the NFC security badge that prompted the access request.

The format of an ACCESS\_REQUEST message is shown in figure
\ref{fig:msg-frmt-access-req}.

\begin{figure}[h]
\centering
\begin{bytefield}[bitwidth=0.03\linewidth]{32}
    \bitheader{0-31} \\
    \wordbox{1}{Message Type} \\
    \wordbox{1}{Transaction ID} \\
    \wordbox{4}{NFC Security Badge ID} \\
\end{bytefield}
\caption{Format of Access Request Message}
\label{fig:msg-frmt-access-req}
\end{figure}

\paragraph{ACCESS\_RESPONSE}
This message is sent by the control server in response to an access request. The
message contains a 32 bit transaction ID which must correspond to the ID from an
ACCESS\_REQUEST message send by the door node and a flag which indicates whether
access should be granted. Bits 33 to 63 of this message type are unused.

The format of an ACCESS\_RESPONSE message is shown in figure
\ref{fig:msg-frmt-access-resp}.

\begin{figure}[h]
\centering
\begin{bytefield}[bitwidth=0.03\linewidth]{32}
    \bitheader{0-31} \\
    \wordbox{1}{Message Type} \\
    \wordbox{1}{Transaction ID} \\
    \bitbox{1}{\tiny{Rsp.}} &
        \bitbox{31}{\color{lightgray}\rule{\width}{\height}}
\end{bytefield}
\caption{Format of Access Response Message}
\label{fig:msg-frmt-access-resp}
\end{figure}

\paragraph{INFORMATION\_REQUEST}
This message is sent by the control server when it requires more information in
order to make an access decision. The message contains a 32 bit transaction ID
and a 32 bit information type value. The possible information types are listed
in table \ref{tab:msg-info-req-types}.

The format of an INFORMATION\_REQUEST message is shown in figure
\ref{fig:msg-frmt-info-req}.

\begin{figure}[h]
\centering
\begin{bytefield}[bitwidth=0.03\linewidth]{32}
    \bitheader{0-31} \\
    \wordbox{1}{Message Type} \\
    \wordbox{1}{Transaction ID} \\
    \wordbox{1}{Information Type} \\
\end{bytefield}
\caption{Format of Information Request Message}
\label{fig:msg-frmt-info-req}
\end{figure}

\begin{table*}[htb]
\centering
\begin{tabular}{@{}ll@{}}
\toprule
Value               &   Description \\
\midrule
0x0                 &   Reserved for future use \\
0x1                 &   Request user temperature \\
0x2 through 0xFFFF  &   Reserved for future use \\
\bottomrule
\end{tabular}
\caption{Information Request Types}
\label{tab:msg-info-req-types}
\end{table*}

\paragraph{INFORMATION\_RESPONSE}
This message is sent by a door node in response to an INFORMATION\_REQUEST
message. The message contains a 32 bit transaction ID, the 32 bit specifier for
the type of information requested (as specified in table
\ref{tab:msg-info-req-types}) and the requested data.

The format of the data returned will depend on the information type. For user
temperature information, the information payload will be 32 bits long. The first
16 bits will be a signed integer in two's complement format indicating the
ambient temperature in units of one hundredth of a degree Celsius per least
significant bit. The second 16 bits will be a signed integer in two's complement
format indicating the temperature of the user in units of one hundredth of a
degree Celsius per least significant bit.

The format of an INFORMATION\_RESPONSE message is shown in figure
\ref{fig:msg-frmt-info-resp}.

\begin{figure}[h]
\centering
\begin{bytefield}[bitwidth=0.03\linewidth]{32}
    \bitheader{0-31} \\
    \wordbox{1}{Message Type} \\
    \wordbox{1}{Transaction ID} \\
    \wordbox{1}{Information Type} \\
    \wordbox[tlr]{1}{Information Payload} \\
    \wordbox[blr]{1}{$\cdots$} \\
\end{bytefield}
\caption{Format of Information Response Message}
\label{fig:msg-frmt-info-resp}
\end{figure}

\paragraph{DOOR\_STATE\_UPDATE}
This message can be sent by the control server to a door node to provide it with
information about the state of the system. This information can be used by the
door node to decide what information to display to users. This state value is
encoded as a 32 bit unsigned integer. The possible state values are listed in
table \ref{tab:msg-door-states}.

The format of an DOOR\_STATE\_UPADTE message is shown in figure
\ref{fig:msg-frmt-door-state}.

\begin{figure}[h]
\centering
\begin{bytefield}[bitwidth=0.03\linewidth]{32}
    \bitheader{0-31} \\
    \wordbox{1}{Message Type} \\
    \wordbox{1}{Door State} \\
\end{bytefield}
\caption{Format of Door State Update Message}
\label{fig:msg-frmt-door-state}
\end{figure}

\begin{table*}[htb]
\centering
\begin{tabular}{@{}ll@{}}
\toprule
Value               &   Description \\
\midrule
0x0                 &   Reserved for future use \\
0x1                 &   Allowing entry \\
0x2                 &   Not allowing entry \\
0x3 through 0xFFFF  &   Reserved for future use \\
\bottomrule
\end{tabular}
\caption{Door State Values}
\label{tab:msg-door-states}
\end{table*}

\subsection{Database Schema}

% This is how you refer to your figure
As seen in Figure \ref{fig:db-schema}

\begin{figure}[!htb]
\centering
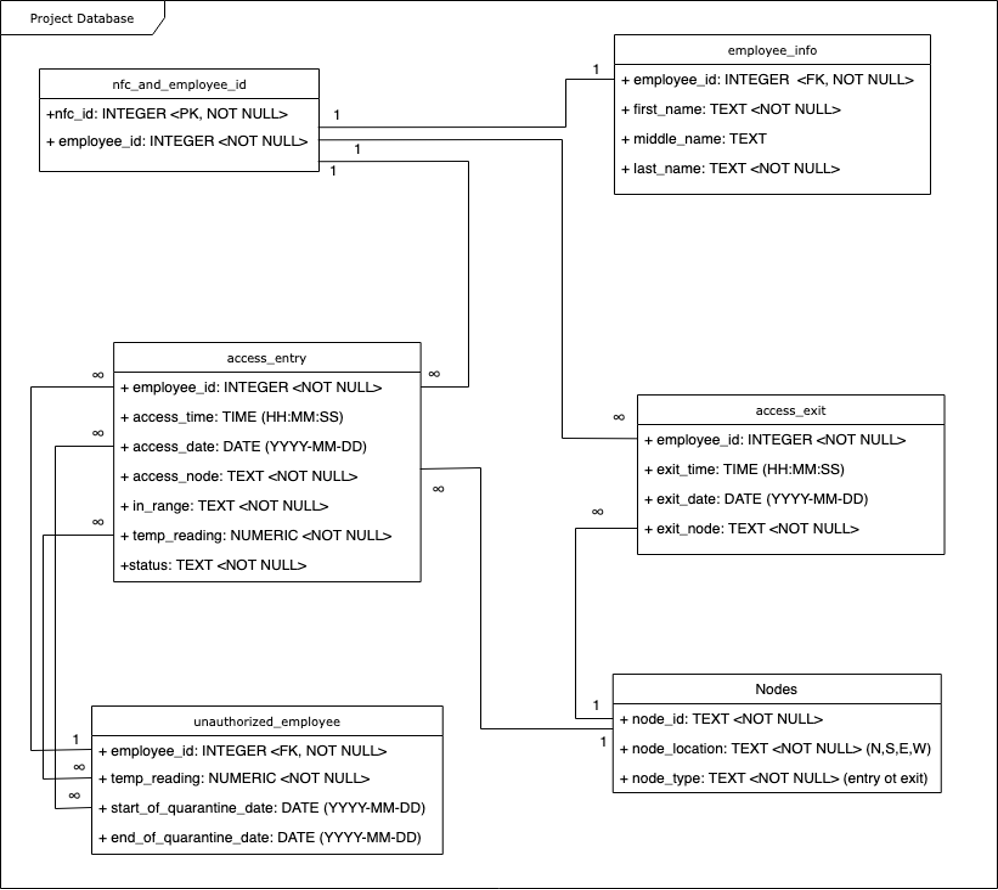
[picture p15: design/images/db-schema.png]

\caption{Database Schema}
\label{fig:db-schema}
\end{figure}

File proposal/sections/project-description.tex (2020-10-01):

Group L3-T-2
\begin{itemize}
    \item Samuel Dewan
    \item Sujeevani Pujari 
    \item Mario Shebib 
    \item Morgan Smith
\end{itemize}

\subsection{About Us}

As COVID-19 concerns bring everyday life all over the world to a standstill, our
team consisting of Carleton Engineering students, works towards tackling these
challenges and making life easier for consumers everywhere.

\subsection{The Team Project} 

As Governments proceed to re-open workplaces, how effective are the risk
management protocols implemented by employers? Are employers prepared for the
employees to come back? How can we be more aware and not panic in implementing
proper entry way guidelines to eliminate the risk of COVID-19? As people
around the world face these challenges everyday, our team works towards
providing the ultimate solution to following proper call-in procedures. We bring
to you a system that looks after the well being of your employees and follows
government regulated infection prevention policies, practices and guidelines for
workplaces. 

This Project will be designed to meet the needs of employers to look after the
safety of their employees. Although not in the scope of the project, our system 
would work with employers to comply with their standards and constraints to 
provide their employees access to a COVID-19 free workplace. As studies 
show that fever ($<$ 39.1 \textdegree C) is the most frequent symptom in more 
than 50\% of COVID-19 cases \cite{Michelen_2020}, our system prevents entry 
to employees that present symptoms of COVID-19. Additionally, our system 
adheres to social distancing guidelines implimented by the government and
restricts access to reduce the spread of COVID-19. With many more features and
benefits, implementing our system at workplaces around the world, successfully
helps in providing a COVID-19 free work environment for employees. 

\subsection{Project Features}

Our revolutionary access control system will:
\begin{itemize}
    \item Display a green light at the entrance if it is accepting people
    \item Be equipped with a Near Field Communication (NFC) security badge
          reader
    \item Recognize employees based on their NFC security cards presented to
          the reader 
    \item Measure the body temperature of an employee trying to enter the work
          premises 
    \item Prevent access to employees with a fever
    \item Keep track of employee details such as their body temperature
          measurement for last 14 days
    \item Track and limit the maximum number of people in an area and display a
          red light at the entrance when the area has reached capacity
    \item Send SMS and email notifications on system failure
    \item Send SMS and email notifications when building is near capacity
    \item Send SMS and email notifications to users when their
          quarantine period is complete
\end{itemize}

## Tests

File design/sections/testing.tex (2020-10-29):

\subsection{End to End Demo}

\noindent
Hardware requirements:
\begin{itemize}
    \item Setup Raspberry Pi's in headless mode 
    \item Connect sensors to Raspberry Pi's
    \item If available, connect LED displays to Raspberry Pi
\end{itemize}

\noindent
Software requirements:
\begin{itemize}
    \item Set up Thingspeak channel 
    \item Hard code sensor signal communication to Thingspeak 
    \item Have test stubs which emulate the functionality of the hardware
          components ready
\end{itemize}

\subsubsection*{Entry Access}

\paragraph{Scenario 1}
Employee with valid NFC card, normal body temperature and ideal distance away
from temperature sensor at entry node.

\noindent
Features to be tested:
\begin{itemize}
    \item Communication between the NFC card reader and Thingspeak 
    \item Communication between control server and Thingspeak
    \item Communication between Time of Flight range finder and Thingspeak 
    \item Communication between Time of Flight range finder and Thingspeak 
    \item Communication between LED display and Thingspeak 
    \item Communication between Temperature sensor and Thingspeak 
    \item Communication between control server and database
    \item Communication between Thingspeak and the electronic lock at entry node
\end{itemize}

\noindent
Test scenario steps:
\begin{enumerate}
    \item Control server uses Thingspeak to send the LED display a signal to
          display green light to indicate door node accepting entries
    \item NFC reader identifies NFC id card being tapped and notifies control
          server of access attempt
    \item NFC reader identifies tapped NFC card id and reports the id to the
          control server
    \item Control server recognizes employee id based on NFC card id
    \item Control server signals the rangefinder to identify if employee in
          range of temperature sensor through Thingspeak
    \item Range finder reports back to the control server with the results and
          displays orange light
    \item When in range, the control server sends a signal to the temperature
          sensor to measure employee body temperature through Thingspeak
    \item Temperature sensor sends the recorded temperature to the control
          server using Thingspeak
    \item Control server saves the recorded temperatures and other required
          information into the database
    \item Control server compares recorded temperature to acceptable temperature
          range
    \item If in acceptable temperature range, control server authorizes employee
          to enter building through Thingspeak
    \item Control server sends a signal to the led display to display a flashing
          green light to indicate employee's access has been authorized
    \item Control server signals the electronic lock to unlock and adds 1 to
          number of people on the premises through Thingspeak
    \item Control server uploads the additional entry attempt recorded data to
          database
\end{enumerate}

\noindent
Expected test scenario result: proper communication between nodes and control
server occurred to authorize employee access to the workplace.

\paragraph{Scenario 2}
Employee with valid NFC card, normal body temperature and not in ideal distance
range away from temperature sensor at entry node.

\noindent
Features to be tested:
\begin{itemize}
    \item Communication between the NFC card reader and Thingspeak
    \item Communication between control server and Thingspeak
    \item Communication between Time of Flight range finder and Thingspeak 
    \item Communication between LED display and Thingspeak 
    \item Communication between Thingspeak and the electronic lock at entry node
\end{itemize}

\noindent
Test scenario steps:
\begin{enumerate}
    \item Control server uses Thingspeak to send the LED display a signal to
          display green light to indicate door node accepting entries
    \item NFC reader identifies NFC id card being tapped and notifies control
          server of access attempt
    \item NFC reader identifies tapped NFC card id and reports the id to the
          control server
    \item Control server recognizes employee id based on NFC card id
    \item Control server signals the range-finder to identify if employee in
          range of temperature sensor through Thingspeak
    \item Range finder reports back to the control server with the results and
          displays red light to let employee know to stand in ideal range away
          from the temperature sensor
    \item Control server signals electronic lock to stay locked through
          Thingspeak
\end{enumerate}

\noindent
Expected test scenario result: proper communication between nodes and control
server occurred to let the employee know to stand in an ideal distance range
away from the temperature sensor.

\paragraph{Scenario 3}
Employee with valid NFC card, body temperature over 39.1 °C and in ideal
distance range away from temperature sensor at entry node.

\noindent
Features to be tested:
\begin{itemize}
    \item Communication between the NFC card reader and Thingspeak 
    \item Communication between control server and Thingspeak
    \item Communication between Time of Flight range finder and Thingspeak 
    \item Communication between LED display and Thingspeak 
    \item Communication between Temperature sensor and Thingspeak 
    \item  Communication between the GUI and Thingspeak
    \item Communication between control server and database
    \item Communication between Thingspeak and the electronic lock at entry node
\end{itemize}

\noindent
Test scenario steps:
\begin{enumerate}
    \item Control server uses Thingspeak to send the LED display a signal to
          display green light to indicate door node accepting entries
    \item Identify tapped NFC card id
    \item Notify control server of access attempt
    \item NFC reader recognizes employee id based on NFC card id and reports to
          control server through Thingspeak
    \item Control server signals the range-finder to identify if employee in
          range of temperature sensor through Thingspeak
    \item Range finder reports back to the control server with the results and
          displays orange light if employee in range of the temperature sensor
          and red light if employee not in range 
    \item When in range, the control server sends a signal to the temperature
          sensor to measure employee body temperature through Thingspeak
    \item Temperature sensor sends the recorded temperature to the control
          server using Thingspeak
    \item Control server saves the recorded temperatures and other required
          information into the database
    \item Control server compares recorded temperature to acceptable temperature
          range
    \item If not in ideal temperature range, control server restricts employee
          from entering the building through Thingspeak
    \item Control server sends a signal to the led display to display a flashing
          red light to indicate employee's access has been unauthorized
    \item Control server sends a quarantine approval notification to the GUI
          through Thingspeak
    \item User approves the quarantine period notification
    \item Approval is sent to the control server through Thingspeak from the GUI
    \item Control server adds the employee information and recorded data to
          unauthorized employee table in the database and marks entry access
          date as the start of quarantine date 
    \item Using Thingspeak the control server signals the electronic lock to
          stay locked 
    \item Control server uploads the additional entry attempt recorded data to
          database
\end{enumerate}

\noindent
Expected test scenario result: proper communication between nodes and control
server occurred to unauthorize employee access to workplace.

\subsubsection*{Exit Access}

\paragraph{Scenario 1}
Employee with valid NFC card and at exit node.

\noindent
Features to be tested:
\begin{itemize}
    \item Communication between the NFC card reader and Thingspeak
    \item Communication between the control server and Thingspeak
    \item Communication between Thingspeak and the electronic lock at exit node 
\end{itemize}

\noindent
Test scenario steps:
\begin{enumerate}
    \item NFC reader identifies NFC id card being tapped and notifies control
          server of exit attempt
    \item NFC reader identifies tapped NFC card id and reports the id to the
          control server
    \item Control server recognizes employee id based on NFC card id 
    \item Control server logs the data recorded for the exit attempt and updates
          the database 
    \item Control server signals the electronic lock to unlock and subtracts 1
          from the number of people on the premises through Thingspeak
\end{enumerate}

\noindent
Expected test scenario result: employee successfully exits the building.

\subsection{Hardware Testing Demo}

\subsubsection{Infrared Temperature Sensor}

\begin{table*}[htb]
\centering
\begin{tabular}{>{\centering\arraybackslash}m{0.75cm}|>{\centering\arraybackslash}m{4cm}|>{\centering\arraybackslash}m{4.5cm}|>{\centering\arraybackslash}m{4cm}}
\toprule
Test & Description & Setup & Expected Result \\
\midrule
1 & Measure a temperature within the normal range & Aim temperature sensor at
someone's forehead and take a measurement & Measured temperature value is within
the expected range \\
\hline
2 & Measure a temperature that could indicate a fever & Aim the temperature
sensor at a pot of water that has been heated to 39 ℃ and take a measurement &
Measured temperature value should be with 0.5 ℃ of 39 ℃. \\
\hline
3 & Measure a temperature below the expected range & Aim the temperature sensor
at any room temperature surface and take a measurement & The measurement should be
approximately room temperature. \\
\bottomrule
\end{tabular}
\caption{Infrared Temperature Sensor Tests}
\label{table:ir-tests}
\end{table*}

\subsubsection{NFC Security Badge Reader}

\begin{table*}[htb]
\centering
\begin{tabular}{>{\centering\arraybackslash}m{0.75cm}|>{\centering\arraybackslash}m{4cm}|>{\centering\arraybackslash}m{4.5cm}|>{\centering\arraybackslash}m{4cm}}
\toprule
Test & Description & Setup & Expected Result \\
\midrule
1 & Green RGB LED functions & Have breadboard set up & Green is shown on LED \\
\hline
2 & Red RGB LED functions & Have breadboard set up & Red is shown on LED \\
\hline
3 & Green RGB LED can change to red & Have breadboard set up & Initially green
is shown on LED which then changes to red \\
\hline
4 & Red RGB LED can change to green & Have breadboard set up & Initially red is
shown on LED which then changes to green \\
\hline
5 & MFRC 522 RFID Module activates & Have breadboard set up. Have a passive tag
ready to wave in front & Pi prints out data on RFID tag \\
\hline
6 & MFRC 522 RFID Module can note separate ID & Have breadboard set up. Have two
passive tags ready to wave in front & Pi prints out different data for each RFID
tag swiped in front. \\
\hline
7 & MFRC 5222 RFID Module will not read when RGB LED is red & Have breadboard
set up. Have a passive tag ready to wave in front & RGB LED is red and no data
is printed out by the Pi. \\
\bottomrule
\end{tabular}
\caption{NFC Security Badge Reader Sensor Tests}
\label{table:nfc-tests}
\end{table*}

\subsubsection{Electronic Door Lock}

\begin{table*}[htb]
\centering
\begin{tabular}{>{\centering\arraybackslash}m{0.75cm}|>{\centering\arraybackslash}m{4cm}|>{\centering\arraybackslash}m{4.5cm}|>{\centering\arraybackslash}m{4cm}}
\toprule
Test & Description & Setup & Expected Result \\
\midrule
1 & Test servo Oscillation & Have breadboard set up & Servo alternates between
0 degrees and 180 degrees every second \\
\bottomrule
\end{tabular}
\caption{Electronic Door Lock Tests}
\label{table:servo-tests}
\end{table*}

A test program will be written that will initially place the servo at an angle
of 0 degrees.  Then a loop will run that will move the servo arm to 180 degrees,
wait a second, move back to 0 degrees, and wait another second.  The operation
of the servo can be easily verified visually.

\subsubsection{Time of Flight Range Sensor}

\begin{table*}[htb]
\centering
\begin{tabular}{>{\centering\arraybackslash}m{0.75cm}|>{\centering\arraybackslash}m{4cm}|>{\centering\arraybackslash}m{4.5cm}|>{\centering\arraybackslash}m{4cm}}
\toprule
Test & Description & Setup & Expected Result \\
\midrule
1 & Orange\_LED function activated & Have LED display set up with the Raspberry
Pi connected to monitor & RGB LED displays Orange \\
\hline
2 & Red\_LED function activated & Have LED display set up with the Raspberry Pi
connected to monitor & RGB LED displays Red \\
\hline
3 & Switch between orange and red LEDs & Have LED display set up with the
Raspberry Pi connected to monitor & RGB LED initially displays orange and then
switches to display red \\
\hline
4 & Switch between red and orange LEDs & Have LED display set up with the
Raspberry Pi connected to monitor & RGB LED initially displays red and then
switches to display orange \\
\hline
5 & VL6180X module activated & Have sensor connected to the Raspberry Pi and
connect Raspberry Pi to a display & Display prints out initial reading \\
\hline
6 & VL6180X module activated and Range\_Find class used to display multiple
range recordings & Have sensor connected to the Raspberry Pi and connect
Raspberry Pi to a display. Keep moving hand over the sensor to be able to
measure range. & Display prints out different readings recorded from moving
hand over the sensor \\
\bottomrule
\end{tabular}
\caption{Time of Flight Sensor Tests}
\label{table:tof-tests}
\end{table*}

\subsection{Database Demo}

The following features are to be tested in order to test the integrity of the
database:

\begin{itemize}
    \item Control server populating right tables 
    \item Proper formatted data uploaded to appropriate fields
    \item Records of the temperature readings of all employees are accessible
          for at least 14 days
\end{itemize}

\paragraph{Scenario 1}
Populating sample test data access\_entry table.

\noindent
Features to be tested:
\begin{itemize}
    \item Control server populating right tables
\end{itemize}

\noindent
Initial setup: set up Raspberry pi connected to monitor keyboard and mouse.
Open command prompt on Raspberry Pi.

\noindent
Test scenario steps:
\begin{enumerate}
    \item Invoke SQLite by typing this command in the command prompt
\begin{lstlisting}
sqlite3
\end{lstlisting}
    \item Open the database by typing this command 
\begin{listing}[H]
\begin{minted}[]{text}
.open project_database.db
\end{minted}
\end{listing}
    \item Populate data to employee access\_entry table
\begin{listing}[H]
\begin{minted}[]{sql}
INSERT INTO access_entry
    VALUES(19234,time('now'),date('now'), "S_entry",
           "Yes", 38.0, "Authorized");
INSERT INTO access_entry
    VALUES(19437,time('now','-12 minutes'),date('now'),
          "E_entry", "Yes", 38.3, "Authorized");
INSERT INTO access_entry
    VALUES(19632,time('now','-1 hour'),date('now'),
           "N_entry", "Yes", 39.2, "Unauthorized");
INSERT INTO access_entry
    VALUES(19957,time('now','-5 minutes'),date('now'),
           "W_entry", "Yes", 38.5, "Authorized");
\end{minted}
\end{listing}
    \item Query data using \lstinline{Select*} command
\begin{listing}[H]
\begin{minted}[]{sql}
SELECT * FROM access_entry;
\end{minted}
\end{listing}
\end{enumerate}

\noindent
Expected test scenario result: table populated with test sample data and query
outputs.

\begin{lstlisting}
19234 | 09:30:23 | 2020-10-26 | S_entry | Yes | 38.0 | Authorized
19437 | 09:18:23 | 2020-10-26 | E_entry | Yes | 38.3 | Authorized
19632 | 08:30:23 | 2020-10-26 | N_entry | Yes | 39.2 | Unauthorized
19957 | 09:25:23 | 2020-10-26 | W_entry | Yes | 38.5 | Authorized
\end{lstlisting}

\paragraph{Scenario 2}
Populating sample test data nfc\_and\_employer\_id table.

\noindent
Features to be tested:
\begin{itemize}
    \item Proper formatted data uploaded to appropriate fields
\end{itemize}

\noindent
Initial setup: set up Raspberry pi connected to monitor keyboard and mouse.
Open command prompt on Raspberry Pi.

\noindent
Test scenario steps:
\begin{enumerate}
    \item Invoke SQLite by typing this command in the command prompt
\begin{listing}[H]
\begin{minted}[]{bash}
sqlite3
\end{minted}
\end{listing}
    \item Open the database by typing this command
\begin{listing}[H]
\begin{minted}[]{sql}
.open project_database.db
\end{minted}
\end{listing}
    \item Populate data to employee access\_entry table
\begin{listing}[H]
\begin{minted}[]{sql}
INSERT INTO access_entry
    VALUES(19234,time('now'),date('now'), "S_entry",
           "Yes", 38.0, "Authorized");
INSERT INTO access_entry
    VALUES(19437,time('now','-12 minutes'),date('now'),
           "E_entry","Yes", 38.3, "Authorized");
INSERT INTO access_entry
    VALUES(19632,time('now','-1 hour'),date('now'),
           "N_entry","Yes", 39.2, "Unauthorized");
INSERT INTO access_entry
    VALUES(19957,time('now','-5 minutes'),date('now'),
           "W_entry","Yes", 38.5, "Authorized");
\end{minted}
\end{listing}
    \item Query data using \lstinline{Select*} command
\begin{listing}[H]
\begin{minted}[]{sql}
SELECT access_time, access_date FROM access_entry;
\end{minted}
\end{listing}
\end{enumerate}

\noindent
Expected test scenario result: table populated with test sample data and query
outputs.

\begin{listing}[H]
\begin{minted}[]{text}
09:30:23 | 2020-10-26
09:18:23 | 2020-10-26
08:30:23 | 2020-10-26
09:25:23 | 2020-10-26
\end{minted}
\end{listing}

\paragraph{Scenario 3}
Populating sample test data access\_entry table.

\noindent
Features to be tested:
\begin{itemize}
    \item Records of the temperature readings of all employees are accessible
          for at least 14 days
\end{itemize}

\noindent
Initial setup: set up Raspberry pi connected to monitor keyboard and mouse.
Open command prompt on Raspberry Pi.

\noindent
Test scenario steps:
\begin{enumerate}
    \item Invoke SQLite by typing this command in the command prompt
\begin{listing}[H]
\begin{minted}[]{bash}
sqlite3
\end{minted}
\end{listing}
    \item Open the database by typing this command
\begin{listing}[H]
\begin{minted}[]{sql}
.open project_database.db
\end{minted}
\end{listing}
    \item Populate data to employee access\_entry table
\begin{listing}[H]
\begin{minted}[]{sql}
INSERT INTO access_entry
    VALUES (19234, time('now'), date('now'), "S_entry",
            "Yes", 38.0, "Authorized");
INSERT INTO access_entry
    VALUES (19437, time('now','-12 minutes'),
            date('now', '-1 day'), "E_entry", "Yes", 38.3,
            "Authorized");
INSERT INTO access_entry
    VALUES (19632, time('now','-1 hour'),
            date('now', '-3 days'), "N_entry", "Yes", 39.2,
            "Unauthorized");
INSERT INTO access_entry
    VALUES (19957, time('now','-5 minutes'),
            date('now', '-7 days'), "W_entry", "Yes", 38.5,
            "Authorized");
INSERT INTO access_entry
    VALUES (19234, time('now'), date('now', '-13 days'),
            "S_entry", "Yes", 38.0, "Authorized");
INSERT INTO access_entry
    VALUES (19437, time('now','-12 minutes'),
            date('now', '-14 days'), "E_entry", "Yes", 38.3,
            "Authorized");
INSERT INTO access_entry
    VALUES (19632, time('now','-1 hour'),
            date('now', '-14 days'), "N_entry", "Yes", 39.2,
            "Unauthorized");
INSERT INTO access_entry
    VALUES (19957, time('now','-5 minutes'),
            date('now', '-15 days'), "W_entry", "Yes", 38.5,
            "Authorized");
\end{minted}
\end{listing}
    \item Query data using \lstinline{Select*} command
\begin{listing}[H]
\begin{minted}[]{sql}
SELECT * FROM access_entry WHERE access_date > date('now');
\end{minted}
\end{listing}
\end{enumerate}

\noindent
Expected test scenario result: table populated with test sample data and query
outputs.

\begin{listing}[H]
\begin{minted}[]{text}
19437 | 09:18:23 | 2020-10-25 | E_entry | Yes | 38.3 | Authorized
19632 | 08:30:23 | 2020-10-23 | N_entry | Yes | 39.2 | Unauthorized
19957 | 09:25:23 | 2020-10-19 | W_entry | Yes | 38.5 | Authorized
19234 | 09:30:23 | 2020-10-13 | S_entry | Yes | 38.0 | Authorized
19437 | 09:18:23 | 2020-10-12 | E_entry | Yes | 38.3 | Authorized
19632 | 08:30:23 | 2020-10-12 | N_entry | Yes | 39.2 | Unauthorized
19957 | 09:25:23 | 2020-10-11 | W_entry | Yes | 38.5 | Authorized
\end{minted}
\end{listing}

\subsection{Final Demo}

Table \ref{table:final-tests} lists the scenarios that we will test during the
final demo. These scenarios have been chosen to demonstrate the functional
requirements as listed in section \ref{sec:problem-statement}.

% Functional requirements:
% - Control access to a building using security badges.
% - Require users to present their security badge when they enter or exit the
%   building in order to track the number of users in the building.
% - Measure user's temperatures when they are entering the building in order to
%   determine if they have possible symptoms.
% - The door node should have a range sensor to determine whether users are in
%   an appropriate position for a temperature reading.
% - Do not allow more users to enter the building if the a preset maximum
%   capacity has been reached.
% - An multicoloured LED at each door node should indicate be used to indicate
%   the status of the door node. The LED should be normally red when the door is
%   locked and should change to green when the door is unlocked. The LED should
%   be orange when in the process of taking a temperature reading if the user is
%   not within an appropriate range of the temperature sensor.
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

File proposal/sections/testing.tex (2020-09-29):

Our project concept has a number of modular components which can be tested
independently. The most critical components will be unit tested while less
critical components will only be tested at a module level due to time
constraints. We will also perform integration testing on the system as a whole.

This section describes the testing approach for each component of the project
and our planned approach to integration testing for the project as a whole.

\subsection{Door Nodes}

The door nodes contain hardware and software components which will need to be
tested individually and as a complete system.

The door node contains three main hardware components for which interface code
will need to be written and tested: the infrared temperature sensor, the NFC
security badge reader and the electronic lock actuator. To ease testing of the
logic and communications portions of the door node software we will write stubs
which emulate the functionality of each these hardware components. Our software
will be architected in such a way that the driver for any hardware component can
be easily replaced with its associated stub and that any combination of stubs
and real hardware can be used.

The hardware interface stubs will create log files that indicate how the
application software has made use of the interfaces provided by the hardware
interface code. They will also support the ability to emulate sensor data or
hardware triggered events based on test data provided as a text file. This
mechanism will be used to when hardware is not available, when testing with real
hardware is too cumbersome and to ensure that the the door node application code
reacts appropriately to invalid or missing data.

\subsubsection{Infrared Temperature Sensor}

\paragraph{Infrared Temperature Sensor Interface Code.}
We will write a minimal test application in order to test the infrared
temperature sensor hardware and interface code separately from the rest of the
system. We will also write unit tests with full line and branch coverage for the
infrared temperature sensor interface code. Some tests will be performed while
monitoring the digital interface of the infrared temperature sensor with a logic
analyzer or oscilloscope in order to verify that the interface code is meeting
the timing requirements of the digital sensor interface.

It will be important to test the hardware and software together to ensure that
we are able to make accurate temperature measurements. While we will be able to
test the sensor on ourselves to ensure that the results we receive are sane, we
need a test rig that is capable of creating arbitrary controllable temperatures
in order to properly test the sensor across the full range of temperatures that
we expect to encounter. Professionally this would be accomplished using a
blackbody calibration source, but these sources cost thousands of dollars. A
makeshift solution which will be sufficient within the scope of our project is
described in the below as part of our proposed approach to sensor calibration.

A stub will be developed that will allow emulated temperature data from a text
file to be fed to the door node application code.

\paragraph{Infrared Temperature Sensor Calibration.}
It is not trivial to achieve medical grade accuracy from an off the shelf
infrared temperature sensor module and some form of calibration will be required
in order to obtain useful readings. While a blackbody calibration source is
prohibitively expensive, for the scope of our project we can make due with a
makeshift calibration solution.

We will calibrate and test our infrared temperature sensors using a pot of water
heated to a target temperature. The infrared temperature sensor will be mounted
at a known height above the water, which will be heated on a stove to the
desired calibration temperature within the range of normal human body
temperatures. The water temperature will be measured with a standard mercury or
digital thermometer.

This solution will give us data for calibration that will be sufficiently
similar to temperature readings from human skin because water and human skin
have similar emissivities in the infrared spectrum. The emissivity of human skin
is roughly 0.98 \cite{Steketee_1973} and the emissivity of water is about 0.993
\cite{Buettner_1965}.

\subsubsection{NFC Security Badge Reader}

We will develop a minimal test application that will allow us to test the NFC
reader hardware and interface code separately from the rest of the system. We
will also write unit tests with full line and branch coverage for the NFC reader
interface code. We will test our interface code using NFC cards that we have
prepared containing both invalid and valid data.

A stub will be developed that will allow emulated NFC security badge data from a
text file to be fed to the door node application code.

\subsubsection{Electronic Door Lock}

A minimal test application will be developed to test the door actuator hardware
and interface code separately from the rest of the system.

A stub will be developed that will allow the door node application code to be
tested without the actuator hardware.

\subsection{Control Server}

In order to test the control server we will use the stubs described in section
\ref{subsec:testing-communication}. This will allow us to thoroughly
exercise the functions of the control server as it is being developed and before
the door node code is complete. This will also allow us to test that the
database and GUI portions of our system are able to support realistically large
numbers of door nodes despite the limited amount of door node hardware that we
have at our disposal.

\subsection{Communication}
\label{subsec:testing-communication}

We will test our communication interfaces by writing a stub application that
emulates one or more door nodes and a stub application that emulates the control
server.

These stubs will make use of our code for interacting with ThingSpeak and the
code that implements our communications protocol. This will allow us to test our
communications code by have the stubs for both sides communicate with each
other. We will also be able to test the control and door nodes of our system in
isolation by using the real code for one node and the stub for the other.

\subsection{Integration Testing}

Integration testing will be performed manually by running the control server and
door node code on real hardware communicating between nodes via ThingSpeak.
Integration testing may be augmented with additional emulated door nodes using
the door node stub.

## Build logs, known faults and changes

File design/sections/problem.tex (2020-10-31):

Our access control system will be designed to meet the needs of employers to
look after the safety of their employees. The scope of this project is to
provide employers with an access control system that grants access to employees
entering the workplace based on their measured body temperature. As studies
show that fever is the most frequent symptom in more than 50\% of COVID-19
cases our system also blocks access to employees with a body temperature
indicating a fever for 14 days to prevent the spread of COVID-19 in the
workplace. Additionally, our system helps building owners adhere to social
distancing guidelines implemented by the government by keeping track of the
number of people on the premises and restricts employees from entering the
building when the maximum threshold for the workplace has been
attained. Although not in the scope of the project, our system would work with
employers to comply with their standards and constraints to provide their
employees access to a COVID-19 free workplace. Our system aims to enable a
COVID-19 free work environment.

Our access control system is a technology-based solution using a data collection
and management system whose primary features and their functionalities include:

\subsection{Functional Requirements}
\begin{itemize}
    \item User should know if door is locked by seeing a red RGB LED
    \item User should know if they are too far away from temperature sensor by seeing an orange RGB LED
    \item User should know if the door is unlocked by seeing a green LED
    \item User should know if the building is at full capacity because of a LED
    \item User should be able to scan ID without touching the NFC reader
    \item Server should know if user is leaving or entering the building
    \item Database should know how many users are in the building
    \item Server user should be able to render invalid ID of ill users
    \item Door lock should unlock when server requests unlock
    \item Server should request temperature sensor data if ID is valid
    \item Server should not request door unlock if user temperature is outside range
    \item Server should request door unlock if user temperature is within range
    \item User should know if the building is at capacity
    \item Time of flight sensor should send to server distance of user from temperature sensor
    \item User should not be able to unlock door if building is at capacity
    \item User should be able to exit if server finds maximum threshold of employees in building
    \end{itemize}
\end{itemize}

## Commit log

2020-09-27 Project description v1.0
    [1] https://www.cebm.net/covid-19/in-patients-of-covid-19-what-are-the-symptoms-and-clinical-features-of-mild-and-moderate-case/
2020-09-29 Update-solution-1
    I made some edits to the Database, communication between nodes and door nodes. I'm not sure what I should write for the sensors subsection to describe them without largely relying on their interactio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
2020-09-29 actuator and GUI changes
2020-09-30 docs: Edit flow of actuator subsection in proposed solution section of proposal
2020-10-27 This has everything I worked on for project Design
    The Project Design.docx has organized everything I think I was supposed to submit.
    The flowchart, class diagram and schematic are also provided bost as .png and as files in the software that created them. I have time tomorrow that if there is a major issue I can work on fixing them. Thank you for your time
    [SYSC3010Schematic.fzz]
2020-10-28 Updated NFC Badge Reader
    Gave a description based on the product data-sheet of why the specific hardware was chosen and reworded to better explain differences between the test circuit and the actual real circuit that I made.
2020-10-28 docs: Electronic lock schematic
2020-10-31 docs: Update hardware schematics and temperature sensor information in design document
